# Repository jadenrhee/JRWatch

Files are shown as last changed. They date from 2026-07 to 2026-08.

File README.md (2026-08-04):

# JRWatch



A smartwatch designed from scratch, board included. 36 mm across and 4
layers, with an nRF52840 for Bluetooth, an nPM1300 handling charging and
the power rails, a BMI270 for motion, and a Sharp memory-in-pixel LCD
that holds a static image on about 12 µW. Firmware runs on Zephyr.

Most of the design work went into idle current, meaning what it draws
while sitting on a wrist doing nothing.

<p align="center">
  front copper
  back copper
</p>
<p align="center"><sub>Front copper on the left, back on the right. 36 x 36 mm, 4 layers.</sub></p>

| | |
|---|---|
| Sleep current | ~15 µA, or ~26 µA while advertising over Bluetooth (1.5 s interval, not connected) |
| Battery life | ~4 months connected to a phone all day, ~8 months mostly idle, on a 150 mAh cell |
| Firmware | Zephyr v4.1.0, 232 KiB flash / 40 KiB RAM |

These are calculated from datasheet typicals, not measured on hardware.
The full itemization is in the
[verification report](docs/verification-report.md). Part choices are in
the [design rationale](docs/design-rationale.md).

## Architecture

```mermaid
flowchart LR
  USB["USB-C"]
  BAT["LiPo 150 mAh<br/>+ 10k NTC"]
  PMIC["nPM1300<br/>charger, 2 bucks,<br/>2 load switches"]
  MCU["nRF52840<br/>MDBT50Q-1MV2"]
  DISP["Sharp LS013B7DH03<br/>128 x 128 MIP"]
  IMU["Bosch BMI270"]

  USB -->|VBUS| PMIC
  BAT -->|VBAT| PMIC
  PMIC -->|3V0 always-on| MCU
  PMIC -->|VDD_DISP via LSW1| DISP
  PMIC -->|VDD_IMU via LSW2| IMU

  MCU -.->|I2C 0x6b| PMIC
  MCU -.->|SPI2| DISP
  MCU -.->|SPI1| IMU
```

Solid lines are power, dashed are data. The display and IMU sit behind
load switches inside the PMIC. In armed sleep they draw about 4 µA and
6 µA. Ship mode disconnects the battery entirely and the whole watch
drops to 370 nA, low enough that cell self-discharge dominates. Full net
list is in [`hardware/skidl/jrwatch.py`](hardware/skidl/jrwatch.py).

<p align="center">
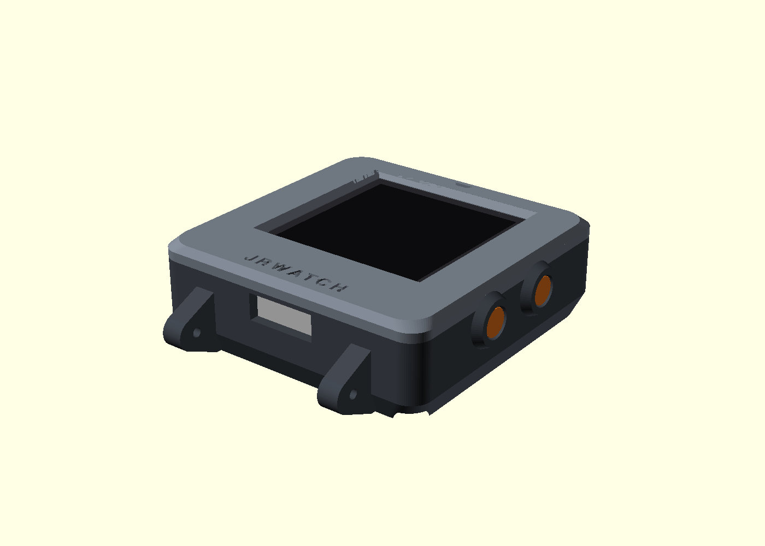
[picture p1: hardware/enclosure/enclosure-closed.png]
case
  
</p>

## Status

Not yet fabricated. A review before ordering turned up a problem with
the display connector, and both halves of it trace to one cause. The
panel's ribbon exits the center and has to fold 180 degrees back
underneath. That fold leaves roughly a 9 mm window where the connector
can sit, and mine was outside it. The fold also inverts the contact
face, which reverses the pin order, and I had the pins running straight
through.

The pin order is corrected in the schematic. Repositioning the connector
is a layout change and hasn't landed yet, so ordering is blocked.
Written up as D-025 in the [decision log](docs/decision-log.md).

## Firmware

An out-of-tree Zephyr board port with devicetree, Kconfig, and board
files. Three power modes cover active, armed sleep, and off. The display
redraws only when its content changes, and the IMU wakes the SoC on
motion. BLE reports battery level and step count
([protocol](docs/protocol.md)).

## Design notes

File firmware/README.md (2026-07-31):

# JRWatch firmware (Zephyr RTOS)

Vanilla-Zephyr application (pinned `v4.1.0` via `west.yml`) with a custom
board definition (`boards/jr/jrwatch/`) that mirrors the schematic pin map
exactly - the devicetree is generated-from/checked-against
`hardware/skidl/jrwatch.py`.

## Build

CI builds every push (`.github/workflows/firmware.yml`, Zephyr CI container).
Locally:

```sh
mkdir jr-ws && cd jr-ws
git clone https://github.com/jadenrhee/JRWatch jrwatch
west init -l --mf firmware/west.yml jrwatch
west update
west build -b jrwatch jrwatch/firmware
west flash   # SWD via TC2030
```

First-time flash is over SWD (Tag-Connect TC2030). USB DFU (MCUboot +
`slot1` partition is already laid out in the devicetree) is the documented
follow-up for cable-only updates.

## How the firmware maps to the power goals

| State | What runs | What's off | Budget driver |
|---|---|---|---|
| **SHIP** | nPM1300 only (battery disconnected from VSYS) | everything | PMIC ship mode ~ sub-µA; exit = SW1 ≥ 96 ms or USB plug |
| **IDLE** ("armed sleep") | nRF System ON idle + RTC (LFXO), BMI270 low-power any-motion @25 Hz, MIP panel statically holding the face, slow BLE adv (1-2 s) | display SPI quiet (image is retained in-pixel), CPU in WFI, BUCK1 off | the headline number - itemized in `docs/verification-report.md` |
| **ACTIVE** | display redraw *only on content change*, IMU 50 Hz, BLE connectable | - | 20 s inactivity drops back to IDLE |

Mechanisms:

- **Hardware power gating**: `VDD_DISP` and `VDD_IMU` are nPM1300 load
  switches (devicetree `npm1300_lsw_disp` / `npm1300_lsw_imu`), driven via
  the Zephyr regulator API. Before cutting the display rail the interface
  lines are quiesced so the unpowered panel is never back-fed (`ui.c`).
- **BUCK1 held off** at boot (`regulator-boot-off` + a runtime check) -
  it is the populated-but-unused 1.8 V experiment rail (decision D-012).
- **Wake sources**: BMI270 INT1 (any-motion) and SW2 both post to a
  `k_event`; between events the idle thread keeps the SoC in System ON idle
  with everything clock-gated. SW1 is wired to the PMIC's SHPHLD only.
- **Display never polled**: the frame is diffed as a string; identical
  content means zero SPI traffic, and the MIP panel holds the image at ~µW
  with the driver toggling EXTCOMIN at 1 Hz.
- **32.768 kHz crystal** (LFXO) for timekeeping and tight BLE sleep-clock
  accuracy - cheaper than LFRC + calibration (decision D-009).
- **Ship mode**: 5 s long-press on SW2, executed from the main loop:
  `regulator_parent_ship_mode()` (TASKENTERSHIPMODE) disconnects the
  battery. On USB power the request is refused up front (the PS forbids
  writing the task with VBUS present); a failed entry recovers the face
  instead of hanging.
- **Battery %**: nPM1300 charger measurements (VBAT/status via sensor
  channels) + an OCV table. Nordic's `nrf_fuel_gauge` (NCS) is the
  higher-accuracy drop-in when building under nRF Connect SDK.

Known follow-ups: on-chip BMI270 step counter (Zephyr driver
doesn't expose it; host-side estimator in `motion.c` meanwhile), BLE
Current Time Service for real wall-clock, MCUboot + USB DFU enablement.

## BLE GATT protocol

Advertises as `JRWatch`, connectable, 1-2 s advertising interval.
Preferred connection parameters 50-100 ms interval, latency 4.

| Service | Characteristic | UUID | Access | Format |
|---|---|---|---|---|
| Battery Service (0x180F) | Battery Level (0x2A19) | standard | read/notify | uint8 % |
| Motion (custom) | - | `6a570000-8f9d-4a7c-9b31-24d1c30f51aa` | - | - |
| | Step count | `6a570001-...` | read/notify | uint32 LE |
| | Activity state | `6a570002-...` | read | uint8 (0 idle / 1 active) |

Console/logs are on SEGGER RTT (no UART pins on the board).

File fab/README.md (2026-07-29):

# Fabrication package

Everything needed to order the JRWatch r1 board from JLCPCB.

## Order parameters (JLCPCB)

| Option | Value |
|---|---|
| Layers | 4 |
| Stackup | **JLC04081H-3313** (0.8 mm finished thickness) |
| Dimensions | 36 × 36 mm, rounded corners R6 |
| Min track/space used | 0.15 mm track / 0.13 mm gap (design rule floor 0.127 mm) |
| Min via | 0.45 mm / 0.2 mm drill (a few 0.48/0.2 vias between QFN pads) |
| Surface finish | **ENIG recommended** (0.5 mm QFN + 0.5 mm FPC pitch) |
| Copper | 1 oz outer / 0.5 oz inner (default) |
| Solder mask | any; silkscreen carries battery polarity + board ID only |

## Files

- `gerbers/` - RS-274X plots (`--no-x2`, mask-subtracted silkscreen) +
  Excellon drill + map. Zip this folder for the JLC order.
- `bom-jlcpcb.csv` - JLC format (`Comment,Designator,Footprint,LCSC`).
  Lines tagged `[HAND-PLACE]` are not for SMT assembly:
  - **U1** MDBT50Q-1MV2 and **U2** nPM1300 - LCSC listed but out of stock at
    design time; source from DigiKey and reflow by hand (module castellations
    iron-friendly; QFN with hot air/plate).
  - **J2** FPC connector - low LCSC stock, order early.
- `cpl-jlcpcb.csv` - pick-and-place. JLC's viewer often needs per-part
  rotation nudges (especially QFN/SOT); footprints should be verified in
  their preview before the order is confirmed.
- `renders/` - top / bottom / iso PNG renders and copper-layer SVGs.
- Connectivity reference for assembly/bring-up: `hardware/netlist/jrwatch.net`
  (generated) - the schematic source of record is `hardware/skidl/`. The old
  `schematic-reference.pdf` was removed: it predated the D-025 J2 pinout fix
  and published the reversed display connector pin order.

## Order status

**This revision is not ready to order.** Pre-order review (D-025) found the
display connector placed out of the panel tail's reach and with un-mirrored
pin order. The schematic is corrected and re-verified; the corresponding
layout rework has not landed yet.

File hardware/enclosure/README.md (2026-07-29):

# Enclosure

Two-piece 3D-printable watch case, written as parametric OpenSCAD
(`jrwatch_case.scad`).
Every cutout is measured from the actual board file: the USB-C slot, the two
side-button bores, and the display aperture. The board has no mounting
holes, so the case clamps it at the four corner arcs, which I verified are
component-free on both sides.

**This revision tracks the pre-D-025 board.** The D-025 layout rework moves
the display connector (and with it the FPC relief, the aperture offset, and
the display mounting stack), so the case geometry and STLs get reworked with
it - don't print or order a set until that lands.

| Exploded | Assembled |
|---|---|
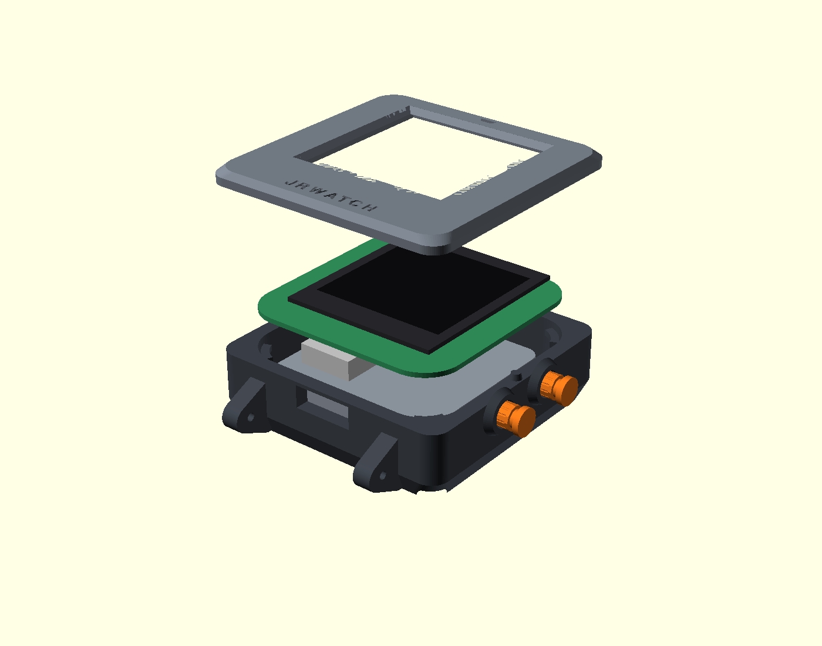
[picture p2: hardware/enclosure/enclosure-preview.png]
exploded
|  | closed |
| **Section through the USB slot** | **Case back** |
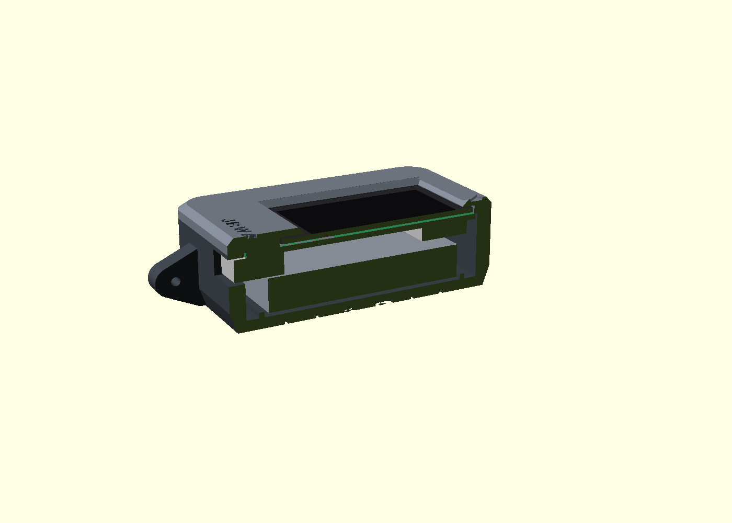
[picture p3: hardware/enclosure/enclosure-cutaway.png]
cutaway
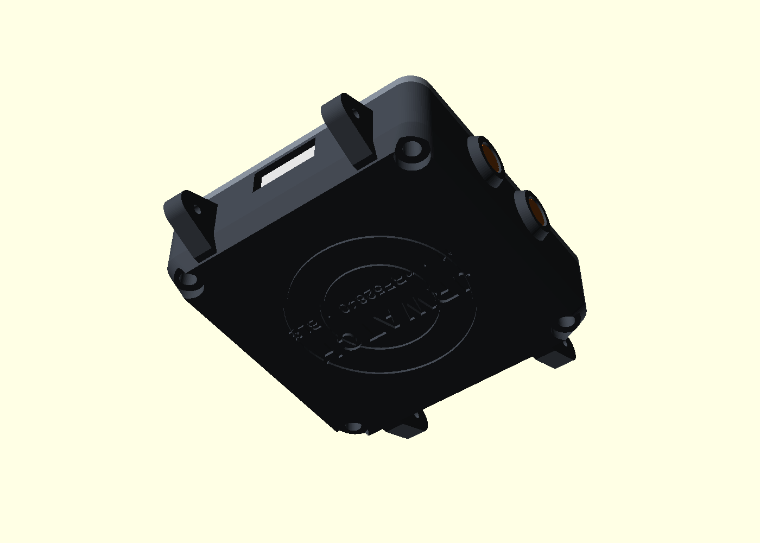
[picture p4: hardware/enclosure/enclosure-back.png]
back
|  |  |

Tapered body with filleted edges, curved lugs drilled for 22 mm spring bars,
knurled sliding pushers in guarded pods, recessed USB-C port. Engraved
12-o'clock index, wordmark, and case back.

## Printed parts (`stl/`)

| File | Qty | What it is |
|---|---|---|
| `case-shell.stl` | 1 | Bottom shell: battery bay, component headroom, USB port, pusher pods, lug horns, engraved back |
| `case-bezel.stl` | 1 | Top ring: display pocket, FPC relief, chamfered aperture, index + wordmark |
| `case-button.stl` | 2 | Knurled sliding pushers (drop into the east-wall bores from the inside) |

Overall 41.4 × 41.4 × 13.6 mm plus lugs. Fits a 22 mm spring-bar strap.

## Ordering online

Upload the three STLs to any print service - [JLC3DP](https://jlc3dp.com)
(same account as the PCB order), Craftcloud, or Shapeways. Choose:

- **Process/material**: MJF or SLS, PA12 nylon (strong, accurate, no
  supports). Gray or dyed black. Expect roughly $5-15 for the set.
- Resin (SLA, "Tough" type) also works and looks smoother; avoid standard
  brittle resin for the lugs.
- FDM at home works if printed shell-open-side-up and bezel-top-down with
  supports in the USB slot; holes may need a 2 mm drill pass.

No metal-plated or metal-filled materials: the BLE antenna sits at the north
edge and the case must stay RF-transparent there.

## Other hardware

| Item | Spec | Note |
|---|---|---|
| Screws ×4 | M2 × 12 mm self-tapping, pan head | enter from the back, bite into the bezel |
| Spring bars ×2 | 22 mm, Ø1.3-1.5 tips | standard watch part |
| Strap | any 22 mm | |
| Display adhesive | 0.3 mm double-sided tape (3M 9448A or VHB) | frame the glass edges, keep the active area clear |
| Battery pad | 1-2 mm foam tape in the battery bay | |

## Assembly order

1. Drop the two button pins into the east-wall bores, flange inward.
2. Battery (502030, PCM-protected) into the bay, pad under it, pigtail up
   to J3 - **check polarity with a meter first** (board silk marks + / −).
3. Board in, components down, USB-C aligned to the south slot. It seats on
   the four corner pads.
4. Fold the display FPC into J2 (contact face up after the fold - J2 is
   top-contact, D-025; flip the latch), tape the
   panel onto the board top with the tail at the south edge.
5. Bezel on, 4 screws from the back. Don't overtighten - stop at contact
   plus a quarter turn.

## Regenerating

```
openscad -D 'PART="shell"'  -o stl/case-shell.stl  jrwatch_case.scad
openscad -D 'PART="bezel"'  -o stl/case-bezel.stl  jrwatch_case.scad
openscad -D 'PART="button"' -o stl/case-button.stl jrwatch_case.scad
```

All key dimensions (stack heights, clearances, lug size) are parameters at
the top of the file.

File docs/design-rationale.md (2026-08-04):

# Design rationale, block by block

Why I picked what I picked. Where there was a real alternative I wrote it
up in `decision-log.md` (the D-numbers below); part sourcing details are in
`hardware/parts.yaml`.

## System architecture

```
USB-C ──► nPM1300 PMIC ──► BUCK2 3.0V (always-on) ──► nRF52840 module
 5V/CC      │  ▲                │                        │  │  │
            │  └─ LiPo 150mAh   ├─ LSW1 ─► VDD_DISP ─► Sharp MIP 128×128
            │     + 10k NTC     └─ LSW2 ─► VDD_IMU  ─► BMI270
            └─ VBUSOUT ─► module VBUS (USB detect/DFU)
```

One always-on rail, two hardware-gated domains, everything else dead in
sleep. If a part can leak current, it doesn't stay electrically attached
while the watch is idle. The sleep numbers follow from that.

## BLE SoC - Raytac MDBT50Q-1MV2 (D-001, D-010)

nRF52840 with the antenna already tuned and certified (FCC/CE/TELEC).
A bare chip + meandered-F antenna needs VNA matching this project can't do;
an untuned antenna silently costs link budget -> retransmissions -> battery.
The module still demands real layout discipline: 61 castellations, a
hard 12.4 × 3.8 mm all-layer keep-out, and radio-adjacent pins that are
restricted to low-frequency signals (datasheet §2.6). The pin map respects
that restriction, with only buttons and EXTCOMIN on those pins. Datasheet:
Raytac spec Ver.K.

## PMIC - Nordic nPM1300 (D-002, D-011, D-012)

One chip covers the whole power path: linear LiPo charger with
NTC/JEITA windows, two 200 mA bucks, two load switches, USB-C sink
detection, ship mode (370 nA), and the measurement chain for Nordic's fuel
gauge. Bucks are asymmetric in their VSET tables, which decided the rail
plan: **BUCK2 = 3.0 V via a 150 kΩ strap is correct at power-on with zero
firmware involvement**; BUCK1 (1.8 V per the reference config) is populated
but held off. The rail is 3.0 V because every load (module 1.7-3.6 V, IMU
1.71-3.6 V, display 2.7-3.3 V typ 3.0) is happy there and it maximizes the
usable LiPo discharge window. Charge current 76 mA ~ 0.5 C for the 150 mAh
pack.

## IMU - Bosch BMI270 (D-003)

The common choice in shipping wearables, picked for its 5.9 µA low-power
accel mode with a hardware any-motion interrupt, so the SoC can stay asleep
until the wrist moves. SPI (not I2C) keeps active-mode transactions short; VDDIO
rides the always-on rail so the interface stays defined while VDD is gated
(explicitly allowed by the datasheet); unused aux/OIS pins strapped per
Table 22.

## Display - Sharp Memory-in-Pixel LS013B7DH03 (D-004, D-013)

Chosen on power. The panel retains its image at 12 µW typical, so the watch
face costs ~4 µA while the system sleeps, with no backlight and readable in
sunlight. A GC9A01-class TFT draws three orders of magnitude more. The costs:
10-pin FPC assembly, a 1 Hz EXTCOMIN toggle (driven by a timer, not the CPU;
EXTMODE strapped high), and 128×128 mono aesthetics. Firmware only redraws
when content changes.

## USB-C (D-015, D-019)

Charge + Full-Speed data (nRF52840 USB for DFU). CC lines go straight to
the nPM1300, which implements Type-C sink detection internally, so the
classic 5.1 k pull-downs would be wrong here, not just redundant. ESD
(USBLC6-2SC6) sits in the data path; VBUS enters through one merged pad
pair (each physical pad on this connector already bridges A/B) with an
IPC-2221-verified width.

## Controls (D-014)

Two side buttons. SW1 goes **only** to the PMIC's SHPHLD pin. That node
swings to VBAT and must never meet an nRF GPIO; it wakes the board from
ship mode in hardware. SW2 is the user button on P1.13 with GPIO SENSE
wake; that pin is one of the radio-restricted low-frequency ones, which is
fine for a button. Both lines: 100 Ω series + SOD-923 TVS sized to their voltage
domains (5 V part on the VBAT-domain node, 3.3 V part on the logic node).

## Timekeeping (D-009)

A watch drifts minutes per week on the RC oscillator; the FC-135-class
32.768 kHz crystal costs two 0402 caps and *saves* current (no periodic
HFCLK calibration, tighter BLE sleep-clock windows -> shorter radio-on).

## Board & layout (D-007, D-020..D-022)

36 × 36 mm R6, 4-layer 0.8 mm (JLC04081H-3313): L1 top = display side +
escape routing, In1 = power pours (3V0/VSYS/VBUS/VBAT), In2 = solid ground,
L4 bottom = components. Antenna strip at the north edge, USB south, buttons
east, battery west, PMIC + inductors clustered with hand-routed switch
loops. The display panel occupies the top face; the FPC connector hides
under its south edge. Silkscreen carries only what matters at assembly:
battery polarity and the board ID.

## Firmware (see firmware/README.md)

Zephyr with a custom board definition pin-mapped 1:1 from the SKiDL source.
Event-driven; three power tiers (ACTIVE / armed-sleep IDLE / PMIC ship
mode); rails gated through the regulator API; display treated as
write-only-on-change. Console over RTT because the design spends no pins on
UART.

## Not included (and why)

- Charge LED (D-016): invisible in a case, and it would wreck the µA budget.
- PPG heart rate (stretch in the brief): omitted to protect the core
  power/size goals; the gated `VDD_IMU` domain and spare module pins are
  where a future MAX30101 daughter experiment would land.
- NFC antenna: module pins exist, but there is no use for it on this product.
- Bare-chip + tuned trace antenna respin: documented stretch once a VNA
  is available (D-001).

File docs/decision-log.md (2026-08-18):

# Decision Log

Every non-trivial design decision, the options considered, and the reasoning.
Priorities used to break ties, in order:

1. **Demonstrable, measured low-power design** (headline metric: sleep current / battery life)
2. **Manufacturability + reliability for a solo builder** (hand-solderable, certified RF, JLCPCB-friendly)
3. **Small, clean, dense layout** (wearable form factor)
4. **Clarity of process/rationale**

---

## D-001: BLE radio - pre-certified module vs. bare nRF52840

- **Options:** (a) Raytac MDBT50Q-1MV2 module (nRF52840 inside, integrated antenna,
  FCC/CE/TELEC certified); (b) bare nRF52840-QIAA + meandered-F trace antenna.
- **Decision: (a) Raytac MDBT50Q-1MV2.**
- **Why:** A trace antenna requires matching-network tuning with a VNA that is not
  available; an untuned antenna silently costs link budget and battery (retransmissions),
  which attacks priority #1. The module is pre-certified (priority #2), still demands
  real high-density layout around its castellations and an antenna keep-out (priority #3),
  and its datasheet gives an explicit keep-out rule that can be *verified* (priority #4).
- **Cost accepted:** ~$6 module premium vs. bare chip; module footprint is larger than a
  bare QFN. Documented stretch goal: respin with bare nRF52840 + tuned antenna once a VNA
  is available.

## D-002: Power management - integrated PMIC vs. discrete chain

- **Options:** (a) Nordic nPM1300 (linear charger + 2 bucks + 2 load-switch/LDOs +
  fuel-gauge measurement chain + USB-C CC detection + ship mode, one QFN32);
  (b) discrete: MCP73831 charger + MAX17048 fuel gauge + low-Iq LDO + discrete load
  switches.
- **Decision: (a) nPM1300**, with (b) held as a logged fallback if LCSC sourcing fails.
- **Why:** Power management *is* the project story. The nPM1300 gives coulomb-counting
  class fuel gauging (VBAT/IBAT/temp measurement feeding Nordic's fuel-gauge algorithm),
  hardware ship mode (~µA off-state), programmable charge current, and two load-switch
  outputs used here to hard-gate the display and sensor rails in ship mode. Gating in
  hardware leaves no sneak paths, so the off-state figure is real rather than
  rhetorical (priority #1). One QFN32 replaces 4+ packages (priority #3) and is a part
  Apple/Nordic-adjacent interviewers recognize (priority #4).
- **Risk accepted:** QFN-32 0.4 mm... *(pitch verified against datasheet in D-010)*
  reflow requires hot-air/stencil rather than an iron; acceptable for a solo builder
  with paste + hot plate, and JLCPCB can assemble it if hand assembly fails (priority #2).

## D-003: IMU - Bosch BMI270

- **Options:** (a) Bosch BMI270; (b) ST LSM6DSO.
- **Decision: (a) BMI270.**
- **Why:** Wearable-industry-standard low-power IMU (5.9 µA low-power accel mode with
  any-motion interrupt - exactly the motion-wake mechanism this design needs), built-in
  step counter offloads counting from the SoC so it can sleep (priority #1), Zephyr has
  an in-tree driver (priority #2), and it connects to hands-on Bosch internship
  experience (priority #4). LSM6DSO is an equivalent fallback if stock fails.

## D-004: Display - Sharp Memory-in-Pixel LCD

- **Options:** (a) Sharp MIP LCD LS013B7DH03 (1.28", 128×128, SPI);
  (b) GC9A01 round TFT (240×240, SPI).
- **Decision: (a) Sharp MIP LS013B7DH03.** *(Supply voltage and FPC pinout verified
  against the Sharp datasheet in D-011 before committing the schematic.)*
- **Why:** Power decides this one. The MIP panel holds a static image at
  single-digit-µW (it only draws meaningful current while lines are being rewritten),
  needs no backlight, and stays readable in daylight, so the watch face costs ~µA
  average. A GC9A01 TFT draws tens of mA with backlight on and ~mA-class even dimmed;
  it would destroy the armed-sleep budget, which is the headline number (priority #1).
  MIP sourcing is via Digi-Key/Mouser/Adafruit rather than LCSC. That is acceptable
  because the display is a hand-attached FPC module, never JLC-assembled; only its
  10-pin FPC *connector* must be LCSC-stocked (priority #2).
- **Logged:** GC9A01 kept as the documented fallback if MIP sourcing collapses.

## D-005: System rails and power-gating topology

- **Options considered:** (a) single 3.0 V always-on buck + load-switch-gated peripheral
  domains; (b) dual rails 1.8 V + 3.3 V both always-on; (c) 1.8 V logic rail + 3.0 V
  peripheral rail.
- **Decision: (a)** BUCK2 = 3.0 V always-on (VSET2 strap = 150k) feeding the MDBT50Q
  (VDD), pull-ups, and bus IO; nPM1300 **LSW1 gates the display** 3.0 V domain and
  **LSW2 gates the IMU (+ future PPG) domain**, both fed from the 3V0 rail. BUCK1 is
  populated but unloaded by default (available as a 1.8 V experiment rail, VSET1 = 47k;
  held off in firmware for production power figures - D-012).
- **Why:** Every always-on rail costs quiescent current; one hysteretic-mode buck is the
  minimum viable always-on domain (priority #1). Full hardware gating of display+sensors
  removes their leakage entirely in ship mode and prevents sneak back-feed
  paths through GPIO (verified in the leakage review). 3.0 V (not 3.3 V) is chosen
  because every load (nRF52840: 1.7-3.6 V, BMI270: 1.71-3.6 V, Sharp MIP: 2.7-3.3 V
  typ 3.0 V) is happy there, it maximizes usable LiPo discharge range through the buck,
  and it is the MIP panel's nominal supply.
- **Nuance logged:** BMI270 VDD could run from a 1.8 V rail for ~40% sensor energy
  savings, but that adds an always-on second buck whose quiescent current exceeds the
  saving at the ~6 µA sensor budget of this design. Rejected on net-µA math.

## D-006: Sleep-state architecture (drives all later verification)

Three power tiers, each with a projected budget to be computed part-by-part in
`docs/verification-report.md`:

1. **Ship / off** - nPM1300 ship mode, SYS rail dead, wake by SHPHLD button only.
   Target: < 1 µA from battery.
2. **Watch idle (armed sleep)** - the headline number. nRF52840 in System ON idle with
   RTC + full RAM retention (BLE off or long-interval advertising), BMI270 in low-power
   any-motion mode (its INT1 wakes the SoC), display statically holding the watch face
   (EXTCOMIN toggled at 1 Hz by the display driver - a periodic ~µs CPU wake), display+IMU
   rails ON but idle. Target: **≤ ~20 µA total** -> months on a 150 mAh cell.
3. **Active** - BLE connected, display refresh on change only, IMU at 50 Hz.

- **Why this structure:** it maps 1:1 to what wearable teams actually ship (off / wrist-
  down / wrist-up), and every number in it is measurable at bring-up with a µCurrent or
  PPK2, so the headline figure can be replaced by a measurement before anyone quotes it.

## D-007: Board format - 4-layer, ~36 mm rounded square, 0.8 mm thick

- **Decision:** 36 × 36 mm rounded-square outline (R = 6 mm), JLCPCB 4-layer,
  **0.8 mm** finished thickness (JLC04081H-3313 stackup), layers:
  L1 components/signal, L2 (In1) power pours, L3 (In2) solid GND, L4
  signal/components.
- **Why:** The Sharp 1.28" panel (~27 × 28 mm active module) sets the minimum face size;
  36 mm is small-watch territory and leaves a real antenna keep-out strip plus button /
  USB edge room (priority #3). A dedicated unbroken GND plane (In2) on the 4-layer
  stack keeps the PMIC switching loops and module grounding verifiable
  (priority #1); 0.8 mm halves stack height in a wearable and is a standard JLC 4-layer
  offering (priority #2). USB is FS-only (12 Mbps) over ~15 mm - controlled impedance
  is not required; the pair is still routed tightly coupled and length-matched as good
  practice.

## D-008: Programming/debug - Tag-Connect TC2030 + USB DFU

- **Decision:** TC2030-IDC-NL footprint (no connector BOM cost, zero height) for SWD,
  plus nRF52840 USB DFU (factory Nordic bootloader is absent on Raytac modules -
  a UF2/MCUboot bootloader is flashed once over SWD, then USB DFU serves daily
  development). Tag-Connect lands on the SWDIO/SWCLK castellations; no 10-pin
  Cortex header fits a 36 mm watch.
- **Why:** Space (priority #3) and solo-builder practicality (priority #2).

## D-009: 32.768 kHz timekeeping crystal - include it

- **Options:** (a) external 32.768 kHz crystal (Epson FC-135 class) on P0.00/P0.01;
  (b) internal LFRC oscillator.
- **Decision: (a) external crystal.**
- **Why:** On a watch, LFRC's ±250 ppm-class error is minutes/week of drift, and
  it costs more current than the LFXO once calibration wakeups are counted
  (LFXO ~ 0.23 µA vs LFRC ~ 0.7 µA + periodic HFCLK calibration bursts on nRF52840).
  Crystal accuracy also tightens BLE sleep-clock windows -> shorter radio-on time per
  connection event (priority #1). Cost: one 3215 crystal + 2 caps (18 pF, set from
  the FC-135 CL spec against nRF52840 pin capacitance - calc in verification report,
  refit in D-026).

---

## D-010: Module sourcing - LCSC listed but out of stock; keep MDBT50Q-1MV2 via DigiKey

- **Finding (2026-07-02):** LCSC lists every Raytac variant - MDBT50Q-1MV2 = C5118826
  ($6.83), P1MV2 = C5119772, U1MV2 = C2688382 - but all show **zero stock**. DigiKey has
  MDBT50Q-1MV2 in stock, ships today.
- **Options:** (a) keep 1MV2, source DigiKey, hand-place; (b) swap to an LCSC-stocked
  non-Raytac module (e.g. Ebyte E73-2G4M08S1C); (c) wait for restock.
- **Decision: (a).** The module's castellated pads are the most iron-friendly
  package on the board, so hand-placing it costs nothing in practice (priority #2
  intact), and Raytac + nRF52840 is the wearable-industry-standard combination the
  project depends on (priorities #1/#4). The KiCad footprint accepts 1MV2 and P1MV2
  interchangeably (identical pads per datasheet §2.1), so a future JLC-assembled run can
  use whichever variant LCSC restocks - C-numbers recorded in `hardware/parts.yaml`.
- **Verified datasheet rules to carry into layout:** antenna keep-out **12.4 mm wide ×
  3.8 mm deep, all layers, no copper**, extending ~1 mm beyond both module sides; plus a
  1.6 × 1.2 mm top-layer-only keep-out notch 2.95 mm from the module's left edge;
  module placed with antenna at the board edge (DS §2.2-2.3, Ver.K).

## D-011: nPM1300 sourcing - same situation, same call

- **Finding:** nPM1300-QEAA-R7 = LCSC C7501206, listed, **zero stock**; WLCSP variant
  (CAAA) in stock but not hand-solderable - rejected. DigiKey: $2.95, ships today.
- **Options:** (a) keep nPM1300, DigiKey, hand hot-air reflow; (b) invoke the discrete
  fallback (MCP73831 + MAX17048 + LDO + 2× load switch, all LCSC basic).
- **Decision: (a).** The fallback would cost the design its ship mode, hardware
  power-gating, coulomb-counting-class fuel gauge, and USB-C detection (i.e. the
  measurable low-power architecture that is priority #1) in exchange for fixing a
  sourcing gap that DigiKey already fills. QFN32 @ 0.5 mm pitch with a 3.5 mm EP
  (PS mech spec) reflows fine with paste + hot plate. The two hand-place lines (U1, U2)
  are exactly the two parts a JLC economic-assembly order can't place today; everything
  else on the BOM is LCSC-stocked, so the board still assembles as
  "JLC does the fiddly passives, builder places two ICs."

## D-012: Rail strapping - BUCK2 is the system rail (3.0 V at power-on, no firmware needed)

- **Finding:** nPM1300 buck startup voltages are strapped by VSET resistors, and the two
  tables are asymmetric: VSET1 tops out at 2.7 V (250-500 kΩ), while **VSET2 = 150 kΩ
  gives exactly 3.0 V** (PS BUCK chapter).
- **Decision:** System 3V0 rail = **BUCK2, VSET2 = 150 kΩ 1%** -> correct-by-hardware at
  first power, no I2C bootstrap dependency for the SoC supply. BUCK1 is populated per
  Nordic reference configuration 1 (L + caps + VSET1 = 47 kΩ -> 1.8 V) but **disabled by
  firmware at init** - it exists as a validated-by-datasheet 1.8 V experiment rail
  without inventing an un-datasheet-ed "unused buck" strapping. Its disable is a checked
  item in the verification report's leakage review.
- **Load switches:** LSW1 ← 3V0 -> display VDD/VDDA; LSW2 ← 3V0 -> IMU VDD.
  (LSIN1/LSIN2 wired from BUCK2 output, load-switch mode, so ship mode can cut both
  domains completely.)

## D-013: Display connector - Hirose FH12A, low stock flagged

- FH12A-10S-0.5SH(55) = C5139870, **91 units** in stock. No drop-in substitute: the
  plain FH12 (C506791) is bottom-contact and cannot mate the folded-under tail (D-025).
  Kept: it's the proven connector for this panel family (Adafruit breakout uses FH12),
  KiCad ships the exact footprint, and the build needs 1-2 units - but flagged in
  `parts.yaml` to order early. Display module itself (LS013B7DH03, VDD 2.7-3.3 V
  verified from Sharp spec §6-1, 12 µW static typ §6-4) ships from DigiKey/Adafruit and
  is hand-attached - never JLC-assembled, so LCSC stock is not required for it.

## D-014: Button architecture - power button on SHPHLD, user button on GPIO

- **Constraint found in PS:** SHPHLD has an internal 50 kΩ pull-up to the battery
  domain - the node swings to VBAT (up to 4.2 V), which exceeds the nRF52840 GPIO
  absolute max (VDD + 0.3 V). The two nets must not share a button naively.
- **Decision:** SW1 = power button -> nPM1300 SHPHLD only (ship-mode exit ≥ 96 ms press,
  also readable as a PMIC event over I2C/GPIO interrupt). SW2 = user button -> nRF
  P1.13 with internal pull-up (uses a radio-adjacent "low-frequency-only" module pin,
  which buttons are perfect for) - GPIO SENSE wakes the SoC from System OFF.
  Both lines get 100 Ω series + a TVS at the switch (user-touchable nets): D2 =
  ESD9B3.3 on the SW2/GPIO line (3V0 domain), D1 = **ESD9B5.0** on the SW1/SHPHLD
  line, since that node rides the battery domain (up to ~5 V), where a 3.3 V-working
  part would sit in clamp. No external pull-ups -> zero standing current either
  way (priority #1).

## D-015: No discrete USB-C CC pull-downs - nPM1300 does Type-C detection

- The task brief specified 5.1 kΩ CC pull-downs; the nPM1300 PS reference circuit
  connects CC1/CC2 straight to the receptacle because the PMIC implements USB Type-C
  sink detection (100/500/1500 mA input-limit negotiation) internally. **Datasheet wins;
  resistors deleted.** Logged as a deliberate deviation from the brief, per its own
  "follow the datasheet, document why" escape hatch.

## D-016: No charge LED

- nPM1300 offers 3 LED drivers; a charge LED at ~2 mA would dwarf the entire sleep
  budget if left on and is invisible inside a watch case anyway. Charge status is
  reported via the fuel-gauge/charger registers -> BLE Battery Service and the
  watch face. PMIC GPIO0 is wired to nRF P0.12 as the charger/fuel-gauge interrupt
  line instead. (Priority #1 over blinkenlights.)

## D-017: On-board NTC (10 kΩ, populated)

- Small hobby LiPo packs frequently omit the thermistor lead; the nPM1300 requires NTC
  or an explicit register disable. Populating a board NTC (Murata NCP15XH103F03RC,
  10 k B3380 1%, placed at the battery connector) keeps hardware charge-temperature
  protection real (JEITA windows in the charger) instead of software-disabled, which
  matters on something strapped to a wrist. If a pack with its own
  NTC is chosen later, the board part is depopulated and the pack lead lands on the
  same net (noted in human-review checklist).

## D-018: Bus strapping and idle-current hygiene

- I2C (PMIC, 400 kHz): 4.7 kΩ pulls to the always-on 3V0 rail - idle-high bus burns
  zero standing current; PMIC must stay reachable in every sleep state, so its bus
  cannot live on a gated rail.
- BMI270 CSB: 100 kΩ pull-up to the always-on 3V0 rail (deselected during nRF reset
  when GPIOs float). The pull is not on the gated rail because CSB must be held
  deselected *before* VDD_IMU comes up; the only state with 3V0 up and VDD_IMU down
  is the millisecond-scale boot window (ship mode kills 3V0 too), so there is no
  steady-state back-feed path through the pull.
- Display SCS: 100 kΩ pull-down (Sharp SCS is active-high; float-low keeps it
  deselected; a pull-down holding an idle-low node costs zero current).
- ASDx/ASCx (BMI270 aux bus, unused): tied to VDDIO per DS Table 22; OCSB/OSDO: DNC.
- All strapping resistors chosen so that **every pull is toward its net's idle state**
  -> 0 µA standing current across the board (verified line-by-line in the report).

## D-019: USB-C VBUS wired at one merged pad pair

- **Finding:** on the HRO 16-pin footprint each *physical* VBUS pad is already
  the merged A/B pair (A4/B9 on one pad, A9/B4 on the other), so a single pad
  delivers VBUS in both plug orientations; the second pad only adds current
  capacity. The west pad is boxed in by an NPTH shell post, the CC2 pad and
  the shield pad - connecting it forced clearance violations in every variant
  tried.
- **Decision (as originally routed):** wire the east pad only (0.3 mm entry + via
  into the In1 VBUS plane); the unwired pad noted here rather than silently left.
- **Superseded during later routing:** a south exit was found for the west pair
  (0.35 mm trace into a via at the connector's south edge), and both merged pad
  pairs are now wired into the In1 plane. The 0.3 mm entry remains the narrowest
  external section of the VBUS path (IPC-2221 calc in the verification report §5).

## D-020: Copper clearance rule 0.15 -> 0.13 mm

- Mid-routing the default clearance was lowered to 0.13 mm (all net classes).
  JLCPCB's 4-layer capability floor is 0.09 mm, so 0.13 keeps ~ 45 % margin
  over fab limits while opening the QFN escape lanes that made the PMIC
  fan-out routable (the 0.5 mm-pitch pad gaps admit 0.48/0.2 mm vias at 0.13,
  not at 0.15). All pre-existing routing was done at 0.15 and passes trivially.

## D-021: Solid zone connections (no thermal reliefs)

- Starved-thermal DRC violations on dense 0402 ground pads were eliminated by
  switching all pours to solid connection. Tradeoff: hand-iron rework of
  ground pads needs more heat; JLC reflow and hot-air work are unaffected.
  Chosen because the alternative (per-pad spoke tuning) added no electrical
  value on a board with a dedicated In2 ground plane.

## D-022: Seven links left open in the U2 south-west quadrant

- Seven links in the congested U2 south-west quadrant could not be closed
  without clearance violations; every attempt collided with other nets'
  copper. Rather than force them in, each was documented with exact endpoints
  and the surrounding copper that blocks it. The board is otherwise DRC-clean
  (zero violations), and the fab README gates ordering on closing them.

## D-023: Review pass closed the three power-critical links

- A dedicated layout review re-attacked the seven open links against a full
  survey of the local copper, instead of the earlier incomplete obstacle
  model. Result: VBAT (pin 19), VSYS pin 20 and VSYS
  pin 4 (PVDD) are now routed and DRC-clean. This took relocating the NTC
  trace out of the south-west slot, one drill resize on a cluster via, a
  via at the VBAT pour edge, a via-less B.Cu path for pin 20 onto existing
  VSYS copper, and an In1 connection lane under the PMIC exposed pad.
  These three links were mandatory: pin 20 is the PMIC's VSYS output, so the
  board was electrically dead without them.
- The remaining four (DISP_SCK, 3V0 to pin 12, SHPHLD, CC2) were also
  attempted: ripping and re-laying 13 corridor nets closed SHPHLD but broke
  I2C_SCL in exchange, so that state was reverted.
  Manual analysis shows each survivor is blocked by locked routing (the
  USB_DP via sits 0.45 mm under pin 12's pad mouth) or requires multi-net
  shoves that could not be made safely without a full re-lay. They stay documented in the review
  checklist with the updated analysis; closing them interactively is the
  remaining pre-order work.

## D-024: Ground-island stitching (correction to earlier assessment)

- The 16 zone-island ratsnest entries were previously described as cosmetic.
  Review showed the opposite: every island carries real component ground
  pads (IMU ground pins, decoupling-cap returns, the USB ESD ground, both
  buttons), which floated without a via to the In2 plane. A clearance-checked
  stitching pass added 13 vias; three
  islands (C1.2, C9.2, C21.2/C22.2 - four capacitor ground pads) have no
  legal via site without moving adjacent routing and are listed in the
  checklist for the same interactive session.

## D-025: Display connector placement and pin order are wrong - found at pre-order review

- Sharp's outline drawing (LS013B7DH03 spec fig 8-1) shows the FPC tail
  **centered** on the panel (13.3 mm from the panel edge) with terminal 1 on
  the **right** in the front view, contacts on the tail's back side, and a
  mandatory fold away from the polarizer. Consequences for this board:
  1. J2 at x=89.3 is unreachable - with the panel on the board, the tail
     center can only fall between x=95.3 and x=104.7. J2 must move to x=100.
  2. After the 180-degree fold the contact face flips up and left-right
     reverses as seen by the connector: pad k must carry panel terminal
     (11-k). The schematic and netlist are corrected (this commit); ERC 0/0.
     The FH12A (top-contact) is the right part for this mounting.
  3. The active area is 1.85 mm north of panel center - enclosure aperture
     offset corrected to 4.2 mm in a follow-up.
- Layout consequences (verified by trial re-route, then reverted to keep the
  board in a known-good state): J2 belongs at pads y~109.8 so its body sits
  between the USB-C shell-leg pairs at (95.7/104.3, 114.65) and the tail
  folds between them; the J2 MP pads need trimming (custom footprint) to
  clear the leg holes; the USB_DM_CONN crossover descent at x=99.85 crosses
  the new pad row and must be redesigned north of y~109; the display fan
  re-routes south from the module (trial run closed it plus SHPHLD and
  I2C_SCL cleanly). Ordering is blocked until this lands.
- Second review session findings (branch `d025-layout-wip` holds the work in
  progress): the USB-C shell has four top-protruding solder slots at
  (95.68/104.32, 110.47 and 114.65) that bracket the whole south strip, so
  the connector cannot sit south of the panel at all. Final verified
  position: J2 at (100, 107.75) - pads y=105.9, body fully under the panel
  (which mounts on 1.2 mm foam so its terminal ledge clears the 1.0 mm body),
  tail folding at the board edge between the leg columns. Proven on the
  branch: J2 placement + mirrored nets, USB CONN highways re-laid at
  y=107.95/108.35, the DM crossover loop, CC2 landing directly on J1.B5 via
  a (98.24, 108.87) via, CC1 landing from the north-east, and a
  zero-violation checkpoint with the display fan, I2C, SHPHLD and CC pair
  routed. Remaining: the south-quadrant fabric (strap highways, DISP_SCK
  east path, 3V0 pin 12, pin 28/29 pocket) needs one interactive-router
  session; every attempt so far has simply undone the one before it.
- **Correction (third pass):** (100, 107.75) does not work with the stock
  FH12 footprint. Its MP tabs span y 108.05-110.25 and J1's pad field starts
  at y 108.83, so the two connectors want the same space. DRC stays quiet
  about it because both nets are GND, which is why the earlier passes read
  as clean. The MP trim this entry already called for is what resolves it:
  tabs re-cut to y 107.00-108.58, clearing J1 by 0.25 mm and keeping
  2.84 mm2 of the 3.96 mm2 anchor by growing north into free space rather
  than only cutting south. Landed with the mirrored pad order on branch
  `d025-rework`, together with DISP_ON, EXTCOMIN, VDD_DISP, DISP_MOSI and
  part of DISP_CS. DISP_SCK, the rest of DISP_CS, 3V0 pin 12, SHPHLD, CC2
  and three GND zone links are still open. Each is blocked by geometry
  rather than effort: U2 is a QFN on 0.5 mm pitch, so nothing fits between
  adjacent pins, and the In1 3V0 pour does not start until x = 100, so a
  via dropped straight under pin 12 lands on the VSYS island instead.
  Closing them means working the corridor east of the pin row by hand.
  Ordering stays blocked.

## D-026: LFXO load caps refit 12 pF → 18 pF (calculation error found on review)

- **What happened:** the original fit used C = 2·(CL - Cs) with Cs = 6.5 pF as a
  *per-side* stray - a formula that only holds when Cs is the lumped parallel
  stray. With per-side stray the crystal sees CL_eff = (C + Cs)/2, so the fitted
  12 pF landed at ≈ 9.25 pF against the Q13FC13500004's 12.5 pF spec - tens of
  ppm fast, seconds per day, on a design that rejected the LFRC over drift
  (D-009).
- **Fix:** C = 2·CL - Cs ≈ 18.5 → **18 pF** (C16/C17), giving CL_eff ≈ 12.25 pF
  under the same stray estimate - and closer to spec than 12 pF for any
  plausible stray, so the swap is safe even though the estimate is soft.
  Changed in the schematic source and parts.yaml; the 18 pF LCSC number gets
  picked and stock-verified at order time. Netlist/board/fab outputs still
  carry 12 pF until they regenerate with the D-025 respin.
- **Verify at bring-up:** measure actual ppm (GPS/NTP comparison over 24 h or a
  counter on the LFCLK test point) before trusting the RTC spec; the pads are
  0402 and a value swap is trivial.

---

*Layout-phase constraint decisions (stackup, keep-outs, netclasses) live in the
build scripts and the verification report; this log records the choices.*

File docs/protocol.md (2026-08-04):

# BLE protocol

Device name `JRWatch`, BLE peripheral, connectable slow advertising
(1-2 s interval). Preferred connection parameters: 50-100 ms interval,
slave latency 4, timeout 4 s, chosen for idle-connected current rather than
latency.

## Services

### Battery Service - standard `0x180F`

| Characteristic | UUID | Access | Format |
|---|---|---|---|
| Battery Level | `0x2A19` | read / notify | uint8, percent |

Fed from the nPM1300 measurement chain (VBAT via the charger's sensor
channels + OCV table; NCS `nrf_fuel_gauge` is the drop-in upgrade).

### Motion Service - custom base `6a570000-8f9d-4a7c-9b31-24d1c30f51aa`

| Characteristic | UUID (short) | Access | Format |
|---|---|---|---|
| Step count | `6a570001-...` | read / notify | uint32 little-endian, steps since boot |
| Activity state | `6a570002-...` | read | uint8: 0 = idle (armed sleep), 1 = active |

Step notifications are emitted only when the value changes and only while a
client has subscribed. There is no periodic radio traffic otherwise.

## Planned (documented, not yet implemented)

- Current Time Service client -> real wall-clock on the face.
- MCUboot + USB DFU for cable updates (flash partitions already laid out).

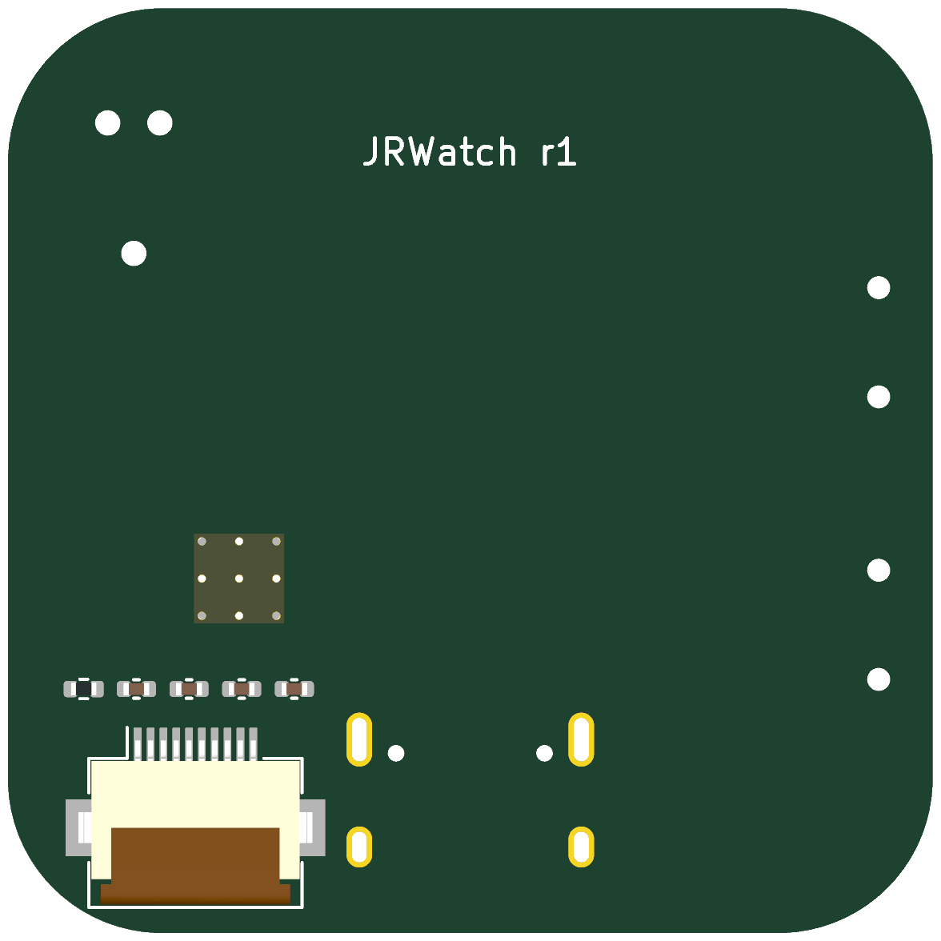
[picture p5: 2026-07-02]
hardware/review/render-top.png

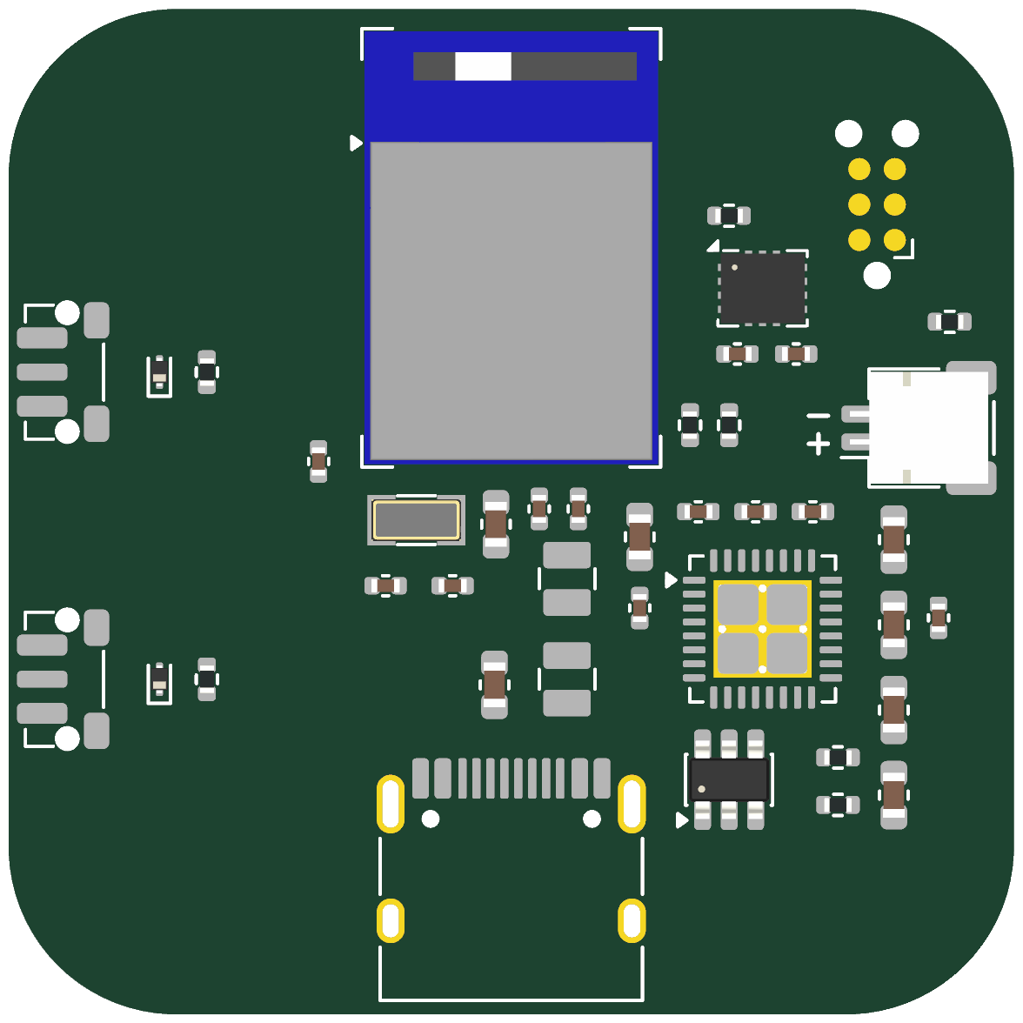
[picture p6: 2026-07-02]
hardware/review/render-bottom.png

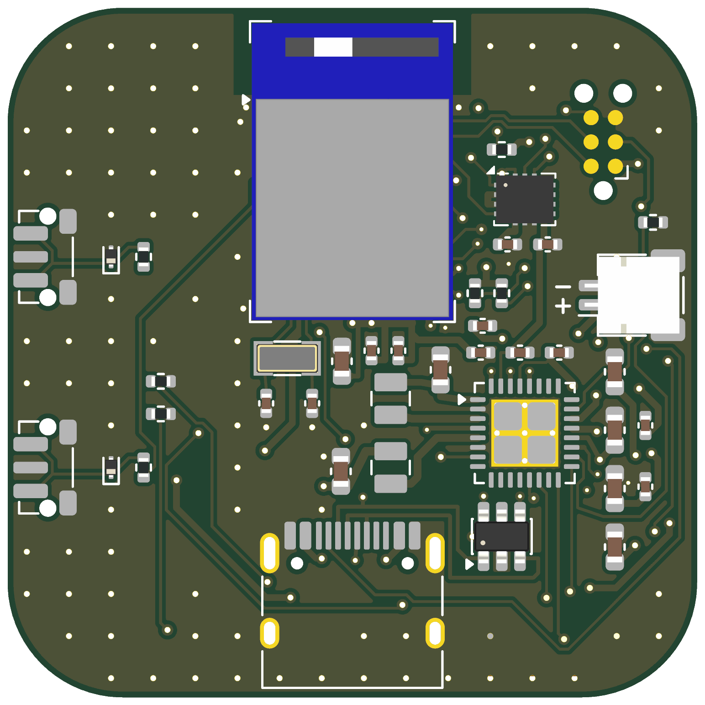
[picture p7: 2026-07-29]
fab/renders/board-bottom.png

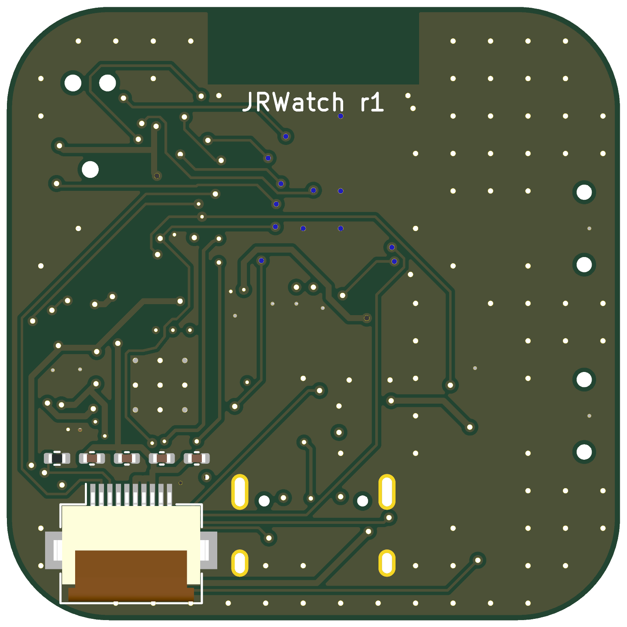
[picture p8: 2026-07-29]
fab/renders/board-top.png

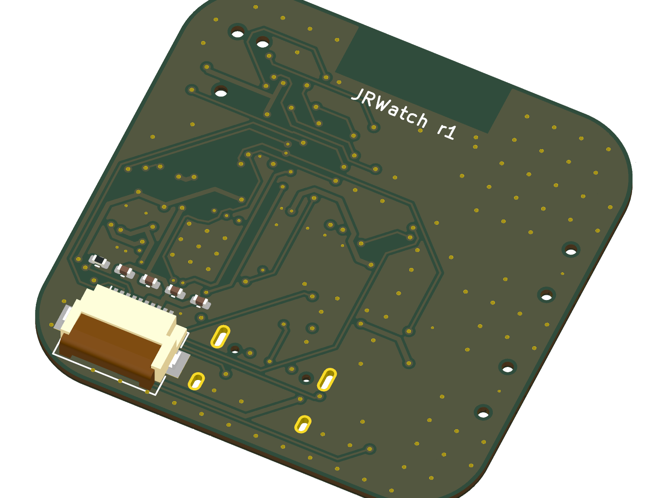
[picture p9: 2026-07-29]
fab/renders/board-iso.png

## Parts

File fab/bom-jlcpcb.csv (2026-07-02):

Comment | Designator | Footprint | LCSC
10uF | C1,C12,C2,C5,C7,C8 | C_0603_1608Metric | C19702
1uF | C10,C20,C22,C6,C9 | C_0402_1005Metric | C52923
100nF | C11,C13,C14,C15,C18,C19,C21,C23,C4 | C_0402_1005Metric | C1525
12pF | C16,C17 | C_0402_1005Metric | C1547
2.2uF | C3 | C_0603_1608Metric | C23630
ESD9B5.0 | D1 | D_SOD-923 | C3008065
ESD9B3.3 | D2 | D_SOD-923 | C96512
TYPE-C-31-M-12 | J1 | USB_C_Receptacle_HRO_TYPE-C-31-M-12 | C165948
FH12A-10S-0.5SH [HAND-PLACE] | J2 | Hirose_FH12-10S-0.5SH_1x10-1MP_P0.50mm_Horizontal | C5139870
SM02B-SRSS-TB | J3 | JST_SH_SM02B-SRSS-TB_1x02-1MP_P1.00mm_Horizontal | C160402
2.2uH | L1,L2 | L_Murata_DFE201612E_2016 | C337893
47k | R1 | R_0402_1005Metric | C25792
150k | R2 | R_0402_1005Metric | C25755
4.7k | R3,R4 | R_0402_1005Metric | C25900
100k | R5,R6 | R_0402_1005Metric | C25741
100R | R7,R8 | R_0402_1005Metric | C25076
10k NTC | RT1 | R_0402_1005Metric | C77131
PWR/SHIP | SW1 | SW_Push_1P1T-MP_NO_Horizontal_Alps_SKRTLAE010 | C110293
USER | SW2 | SW_Push_1P1T-MP_NO_Horizontal_Alps_SKRTLAE010 | C110293
MDBT50Q-1MV2 [HAND-PLACE: DigiKey, LCSC OOS at design time] | U1 | Raytac_MDBT50Q | C5118826
nPM1300-QEAA-R7 [HAND-PLACE: DigiKey, LCSC OOS at design time] | U2 | VQFN-32-1EP_5x5mm_P0.5mm_EP3.5x3.5mm_ThermalVias | C7501206
BMI270 | U3 | Bosch_LGA-14_3x2.5mm_P0.5mm | C2836813
USBLC6-2SC6 | U4 | SOT-23-6 | C7519
32.768kHz | Y1 | Crystal_SMD_3215-2Pin_3.2x1.5mm | C32346

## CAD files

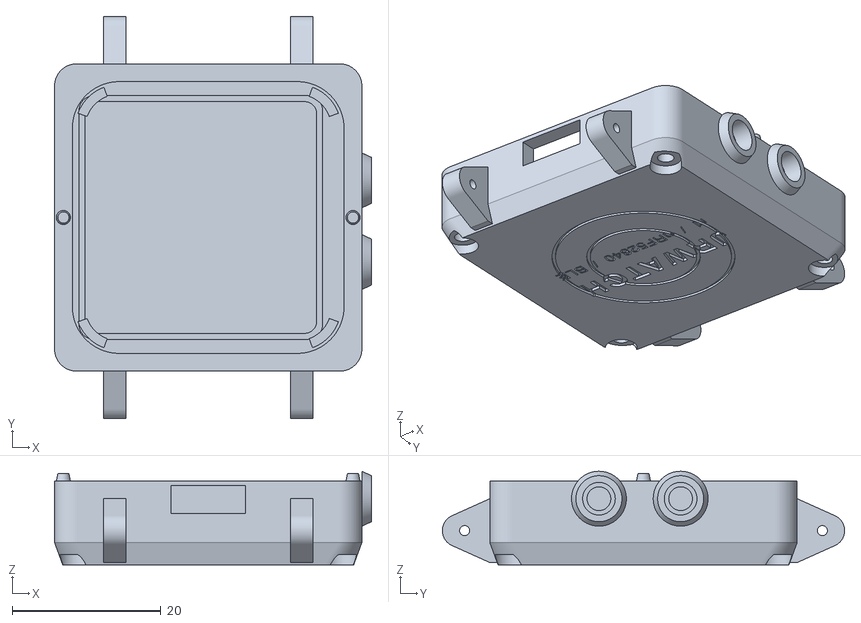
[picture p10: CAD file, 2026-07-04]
hardware/enclosure/stl/case-shell.stl
42.7 x 54.2 x 12.6

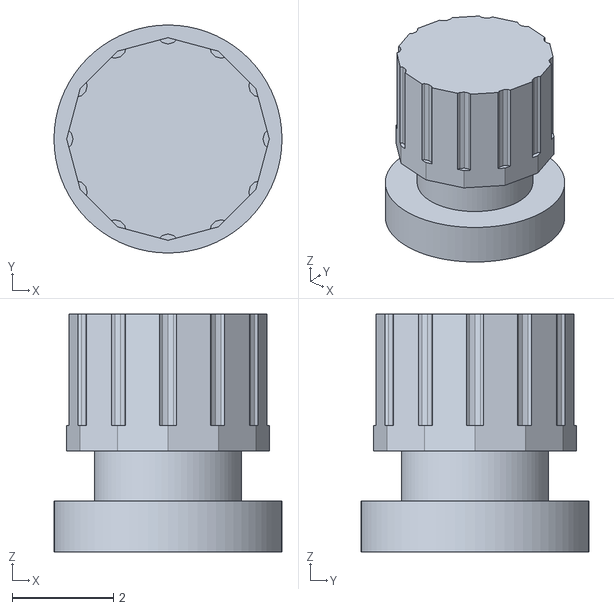
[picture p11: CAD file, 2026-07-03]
hardware/enclosure/stl/case-button.stl
4.50 x 4.50 x 4.69

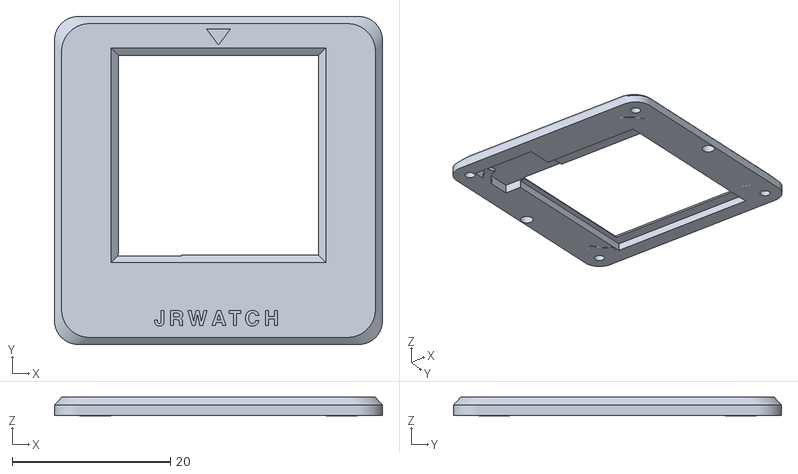
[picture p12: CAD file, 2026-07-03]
hardware/enclosure/stl/case-bezel.stl
41.4 x 41.4 x 2.35

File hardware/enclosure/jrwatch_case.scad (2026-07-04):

// JRWatch enclosure - two-piece 3D-printable watch case
// ------------------------------------------------------
// Dimensions come from the actual board (hardware/jrwatch.kicad_pcb):
//   * board 36 x 36 mm, corner radius 6, thickness 0.8
//   * USB-C on the BOTTOM side, mouth at the south edge, x = 95..105 (board coords)
//   * side buttons SW1/SW2 on the east edge at y = 95 / 106 (board coords)
//   * display LS013B7DH03 on top: 26.6 x 30.3 x 0.74, active 23.04 sq,
//     FPC folds under its south edge into J2
//   * everything else on the bottom, tallest = USB-C shell (3.26)
// Case coordinates: origin at board center, +Y = board north, z=0 case bottom.
//
// Set PART before rendering:
//   "shell"    - bottom case            (print 1x)
//   "bezel"    - top ring               (print 1x)
//   "button"   - side pusher pin        (print 2x)
//   "assembly" - exploded preview       (not for printing)
//   "closed"   - assembled preview
//   "cutaway"  - assembled, sectioned through the USB slot

PART = "assembly";

/* ---------- board & stack ---------- */
board_w   = 36;      // square board edge
board_r   = 6;       // board corner radius
board_t   = 0.8;
clr       = 0.3;     // board-to-case clearance per side

floor_t   = 1.6;
bat_h     = 5.4;     // battery bay: 502030 pouch (5.0) + foam pad
comp_h    = 3.5;     // bottom-component headroom (USB-C shell is 3.26)
bezel_h   = 2.3;     // above board top

z_board   = floor_t + bat_h + comp_h;   // board underside = 10.5
z_part    = z_board + board_t;          // parting line at board top = 11.3
z_top     = z_part + bezel_h;           // 13.6 overall

/* ---------- case body ---------- */
wall      = 2.4;
cav_half  = board_w/2 + clr;            // 18.3
out_half  = cav_half + wall;            // 20.7
out_r     = 3.0;                        // outer corner radius (square-ish corners
                                        // leave meat for the screw bosses)
taper_h   = 3.0;                        // filleted/tapered lower body
taper_in  = 1.1;

/* ---------- screws (M2 x 12 self-tapping, from the back) ---------- */
screw_d    = 17.8;    // hole center at (+/-d, +/-d)
pilot_dia  = 1.7;
shank_dia  = 2.3;
head_dia   = 4.4;
head_h     = 1.4;

/* ---------- display ---------- */
disp_w    = 26.6;                 // x
disp_h    = 30.3;                 // y
disp_t    = 0.74;
disp_tape = 0.3;                  // mounting adhesive under the glass
disp_cy   = (100 - 97.65);        // panel center offset north (board y 82.5..112.8)
ap_size   = 25.2;                 // aperture over the 23.04 active area
ap_cy     = 3.2;                  // active-area center offset north (verify vs
                                  // datasheet fig 8-1 before ordering)

/* ---------- cutouts (from board footprints) ---------- */
usb_w     = 10.0;                 // slot width  (connector 8.94)
usb_zlo   = z_board - 3.6;        // slot bottom (connector hangs 3.26 below board)
usb_zhi   = z_board + 0.2;
btn_hole  = 3.2;                  // pusher pin bore
btn_y     = [ 5, -6 ];            // SW1 (board y=95), SW2 (board y=106)
btn_z     = z_board - 1.6;        // actuator center below the board

/* ---------- strap lugs (22 mm spring-bar strap) ---------- */
lug_gap   = 22.2;                 // between inner prong faces
lug_wide  = 3.0;                  // prong thickness (x)
lug_len   = 5.6;                  // protrusion from wall (y)
bar_hole  = 1.35;                 // spring-bar pin
bar_off   = 3.4;                  // hole center beyond the wall
bar_z     = 4.6;

$fn = 72;
eps = 0.01;

/* ================= 2D helpers ================= */

module rsquare(half, r) { offset(r = r) square(2*(half - r), center = true); }
module cavity2d()  rsquare(cav_half, board_r + clr);
module outer2d()   rsquare(out_half, out_r);

/* ================= shared 3D details ================= */

// crescent screw boss in each corner: post around the screw, clipped so it
// never intrudes on the board's corner arc
module corner_posts(h) {
  for (sx = [-1, 1], sy = [-1, 1])
    scale([sx, sy, 1])
      intersection() {
        linear_extrude(h) intersection() {
          translate([screw_d, screw_d]) circle(d = 5.6);
          cavity2d();
        }
        linear_extrude(h) difference() {
          square(2*out_half, center = true);
          translate([12, 12]) circle(board_r + clr + 0.05);
        }
      }
}

// annular wedge reaching under (or over) the board's corner arc - the board
// is clamped only here; the corner zones are component-free on both sides
module corner_pads(h) {
  for (sx = [-1, 1], sy = [-1, 1])
    scale([sx, sy, 1])
      linear_extrude(h) intersection() {
        translate([12, 12]) difference() { circle(5.9); circle(4.6); }
        translate([12, 12]) rotate(45)
          polygon([[0,0], [10, 4.6], [10, -4.6]]);   // ~50 deg outward wedge
      }
}

// curved watch-style lug horn, drilled for a spring bar
module lug_horn() {
  difference() {
    hull() {
      // root: blends into the case wall
      translate([0, -0.6, 4.6]) cube([lug_wide, 1.2, 8.6], center = true);
      // tip: round horn end
      translate([0, lug_len - 1.4, bar_z])
        rotate([0, 90, 0]) cylinder(h = lug_wide, r = 2.2, center = true);
    }
    translate([0, bar_off, bar_z])
      rotate([0, 90, 0]) cylinder(h = lug_wide + 1, d = bar_hole, center = true);
  }
}

module lugs()
  for (sy = [-1, 1], sx = [-1, 1])
    scale([sx, sy, 1])
      translate([lug_gap/2 + lug_wide/2, out_half - eps, 0]) lug_horn();

// raised pusher guard pods on the east wall
module button_pods()
  for (y = btn_y)
    translate([out_half - eps, y, btn_z]) rotate([0, 90, 0]) {
      cylinder(h = 1.3, d1 = 7.4, d2 = 6.2);
    }

// small alignment nubs on the shell rim (holes in the bezel underside)
nub_p = [[-(cav_half + wall/2), 0], [cav_half + wall/2, 0]];
module rim_nubs()  for (p = nub_p) translate([p[0], p[1], z_part - eps])
                     cylinder(h = 1.0 + eps, d1 = 1.9, d2 = 1.5);

/* ================= bottom shell ================= */

module shell_body() {
  // tapered, edge-filleted lower body flowing into straight walls
  hull() {
    translate([0, 0, 0])       linear_extrude(eps) rsquare(out_half - taper_in, out_r + 0.8);
    translate([0, 0, taper_h]) linear_extrude(eps) outer2d();
  }
  translate([0, 0, taper_h]) linear_extrude(z_part - taper_h) outer2d();
}

module back_engraving() {
  mirror([1, 0, 0]) {                       // reads correctly from outside
    translate([0, 2.6, -eps]) linear_extrude(0.45)
      text("JRWATCH", size = 3.4, font = "Helvetica:style=Bold",
           halign = "center", valign = "center", spacing = 1.15);
    translate([0, -2.6, -eps]) linear_extrude(0.45)
      text("r1  /  nRF52840  /  BLE", size = 1.7, font = "Helvetica",
           halign = "center", valign = "center", spacing = 1.1);
  }
  // decorative recessed rings
  for (r = [7.6, 12.4]) translate([0, 0, -eps]) linear_extrude(0.35)
    difference() { circle(r + 0.25); circle(r - 0.25); }
}

module shell() {
  difference() {
    union() { shell_body(); lugs(); button_pods(); }
    // main cavity
    translate([0, 0, floor_t]) linear_extrude(z_part) cavity2d();
    // screw shank + head pocket
    for (sx = [-1, 1], sy = [-1, 1]) {
      translate([sx*screw_d, sy*screw_d, -eps]) cylinder(h = z_part, d = shank_dia);
      translate([sx*screw_d, sy*screw_d, -eps]) cylinder(h = head_h + eps, d = head_dia);
    }
    // USB-C slot with a port-recess and plug chamfer, south wall
    translate([0, -out_half, (usb_zlo + usb_zhi)/2]) {
      cube([usb_w, 2*wall + 2, usb_zhi - usb_zlo], center = true);
      translate([0, -wall + 0.55, 0]) hull() {
        cube([usb_w + 0.4, wall, usb_zhi - usb_zlo + 0.4], center = true);
        translate([0, -0.9, 0])
          cube([usb_w + 2.4, 0.2, usb_zhi - usb_zlo + 2.2], center = true);
      }
    }
    // stepped pusher bores, east wall (pin inserts from the inside):
    // flange counterbore -> narrow retention bore -> wide channel for the cap
    for (y = btn_y) translate([cav_half - eps, y, btn_z]) rotate([0, 90, 0]) {
      translate([0, 0, -1.2]) cylinder(h = 1.2 + eps, d = 4.9);   // flange seat
      cylinder(h = 1.0 + eps, d = btn_hole);                      // retention bore
      translate([0, 0, 1.0]) cylinder(h = wall + 3, d = 4.4);     // cap channel
    }
    back_engraving();
  }
  // rebuild the corner posts (the cavity cut removed them), minus screw bores
  difference() {
    corner_posts(z_board);
    for (sx = [-1, 1], sy = [-1, 1])
      translate([sx*screw_d, sy*screw_d, -eps]) cylinder(h = z_board + 1, d = shank_dia);
  }
  translate([0, 0, z_board - 1.0]) corner_pads(1.0);   // board rests on these
  rim_nubs();
  // battery fence (502030 pouch + foam pad drop in here)
  translate([-1, 0, floor_t]) linear_extrude(0.8) difference() {
    rsquare(31.2/2 + 0.8, 2);
    rsquare(31.2/2, 1.6);
  }
}

/* ================= top bezel ================= */
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

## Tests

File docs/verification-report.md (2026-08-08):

# Verification Report

This is where I check my own work: every design rule against theory or a
datasheet, with the value and where it came from. Anything marked
**PROJECTED** is calculated from datasheet typicals, not measured. Those get
replaced with real PPK2 measurements at bring-up.

## 1. Headline: power budget and projected battery life

**Projected armed-sleep current: ~ 15 µA (BLE off) / ~ 26 µA (slow advertising).**
**Projected battery life on the 150 mAh cell: ~ 4-8 months per charge in
typical watch use; > 2 years in ship mode (battery self-discharge dominates).**

### Sleep tier budget - "IDLE / armed sleep" (battery side, VBAT = 3.8 V)

Motion-wake armed, watch face statically displayed, RTC running.

| Item | Draw at its rail | Battery-side* | Source |
|---|---|---|---|
| nRF52840 System ON idle, full RAM retention, LFXO + RTC | ~ 3.0 µA @3.0 V | ~ 3.2 µA | nRF52840 PS typicals (ION + RAM retention + ILFXO + IRTC); PROJECTED |
| BMI270 low-power mode, 25 Hz, any-motion armed | 5.9 µA @3.0 V | ~ 6.2 µA | BMI270 DS (BST-BMI270-DS000), low-power mode table |
| Sharp LS013B7DH03 holding static image | 12 µW typ @3.0 V = 4.0 µA | ~ 4.2 µA | Sharp spec §6-4, measurement condition 1 (typ; max 50 µW) |
| nPM1300 quiescent (battery operation) | - | 0.8 µA | nPM1300 PS v1.1 Table 4: IQBAT = 800 nA |
| Strapping/TVS/capacitor leakage | - | ≤ 0.5 µA | D-018: every pull is toward its idle state (0 standing current by design); TVS I_leak ≪ 0.1 µA each |
| **Total (BLE off)** | | **~ 15 µA** | |
| BLE advertising, 1.5 s interval, 0 dBm, DCDC | - | ~ +11 µA | Nordic online power profiler class figure; PROJECTED |
| **Total (slow advertising)** | | **~ 26 µA** | |

\* battery-side = rail current × (3.0 V / 3.8 V) / η, with BUCK2 hysteretic-mode
efficiency taken as η ~ 0.75 at µA loads (PS efficiency curves; PWM-mode spec
is 93 % at 200 mA - light-load hysteretic efficiency is graph-derived and is a
priority bring-up measurement).

### Other tiers

| Tier | Projection | Notes |
|---|---|---|
| Ship mode | 0.37 µA (PMIC) - cell self-discharge (~2-3 %/month) dominates | nPM1300 PS Table 4: IQSHIP = 370 nA; battery fully disconnected from VSYS |
| Hibernate | 0.5 µA | IQSHIPT = 500 nA (wake-timer variant; PMIC capability only - the firmware's three tiers don't use it) |
| ACTIVE (display refresh on change, IMU 50 Hz, BLE connected 100 ms/latency 4) | ~ 250-400 µA avg | dominated by IMU full-ODR (~ 200 µA) + BLE connection events; display redraw is event-driven, ~0 between changes |

### Life projections (150 mAh)

| Profile | Average draw | Projected life |
|---|---|---|
| Armed sleep only, BLE off (worn, no interaction) | 15 µA | ~ 13 months |
| Armed sleep + slow advertising | 26 µA | ~ 240 days |
| Watch use: 30 min/day ACTIVE + advertising idle | ~ 32 µA avg | **~ 6.5 months** |
| Always-connected + hourly interactions | ~ 45 µA avg | ~ 4.5 months |

## 2. RF / antenna - **PASS**

- Keep-out per Raytac Ver.K §2.2-2.3: 12.4 × 3.8 mm, all layers, plus the
  1.6 × 1.2 mm top-layer notch. Implemented three ways and geometrically
  verified from the live board: the module's own two keep-out zones, a
  board-level rule area extending to the edge, and the edge ring. Copper on
  F/In1/In2/B inside the region: **none** (DRC rule areas active throughout
  routing and fills).
- Module placed with the antenna at the board's north edge (Raytac: "place
  the module towards the edge of PCB"). PASS.
- Caveat (checklist §3): keep display tail metal and enclosure screws out of
  the zone too.

## 3. Power / PMIC layout - **PASS with notes**

- Buck loops: SW1/SW2 nodes are 0.4 mm, hand-routed, 4.6 mm long, with the
  output caps (10 µF each) directly at the inductor outputs and PVSS pads on
  the B.Cu ground fill over the In2 plane. Layout follows nPM1300 PS
  reference layout intent. PASS.
- Inductors: 2.2 µH ±20 %, DCR 116 mΩ < 400 mΩ requirement, Isat 2.4 A ≫
  0.2 A buck limit (Murata DFE201612E-2R2M, the part Nordic's EK uses). PASS
  (PS reference BOM).
- Rails: BUCK2 = 3.0 V by VSET2 = 150 kΩ (PS BUCK table) - correct at power-on
  with no firmware dependency; BUCK1 populated per reference config,
  firmware-disabled (D-012, enforced in devicetree + `power.c`). PASS.
- Decoupling: every power pin has its cap; VBUS 10 µF, VBAT 10 µF, VSYS
  10 µF + 2.2 µF, VOUT1/VOUT2 10 µF, VBUSOUT 1 µF, VDDIO 100 nF, LSOUT 1 µF
  each, module VDD 10 µF + 100 nF ×2. Values per PS reference circuitry BOM.
  PASS. *Note:* PVDD's dedicated 100 nF sits on the west bank ~5 mm from the
  pin (pocket congestion); VSYS bulk is 2.6 mm away. Flagged for review.
- **Charge-temperature protection is real hardware**: on-board 10 k B=3380 NTC
  (D-017) matching the devicetree charger config. PASS.
- Load-switch gating: display and IMU rails are LDO1/LDO2 in LDSW mode fed
  from BUCK2 - ship mode can cut both domains to zero. PASS.
- Ground return integrity: review found 16 outer-layer ground islands whose
  component pads had no via to the In2 plane (initially mis-assessed as
  cosmetic). 13 stitch vias added, covering the IMU ground pins, ESD array,
  buttons and most decoupling returns; 3 capacitor islands remain
  (checklist §1). PASS after checklist item closes.

## 4. Sneak-leakage review - **PASS (design), verify at bring-up**

- Every strap pulls toward its net's idle state (D-018): I2C pulls to the
  always-on rail (idle high = 0 µA), CSB pull-up to always-on VDDIO
  (deselected = 0 µA), SCS pull-down (deselected = 0 µA). PASS.
- Display rail off: the panel driver's init is deferred until VDD_DISP is up
  (`zephyr,deferred-init` - at boot nothing drives an unpowered panel), and
  `ui.c` blanks the panel before cutting the rail in the ship path - no
  back-feed through panel input clamps. PASS (code review).
- IMU: VDDIO stays on the always-on rail while VDD is gated - explicitly
  permitted ("no limitations with respect to the voltage level applied to the
  VDD and VDDIO pins", BMI270 DS §POR/supply); interface pins remain defined.
  PASS.
- No LEDs anywhere (D-016). PASS.

## 5. Charge path & IPC-2221 - **external PASS, one In1 neck flagged for the D-025 rework**

Formula: I = k · ΔT^0.44 · A^0.725, k = 0.048 external / 0.024 internal layers.
Worst case is the 500 mA USB input limit (charging + system), ΔT = 10 °C:

- **External sections (1 oz, k = 0.048):** required area
  A = (0.5 / (0.048 × 10^0.44))^(1/0.725) = **6.3 mil²** -> at 1 oz (1.378 mil)
  = **4.6 mil ~ 0.12 mm** minimum width. Implemented: 0.3 mm minimum at the VBUS
  entry (D-019 pinch), 0.35 mm typical on the external runs. **Margin ≥ 2.5×
  on width. PASS.**
- **Internal sections (0.5 oz In1, k = 0.024):** the same formula requires
  **0.60 mm** width for 500 mA at ΔT = 10 °C. The VBUS path's In1 link into the
  PMIC pocket runs **0.35 mm** for ~2 mm outside the In1 pour - that section
  supports ~340 mA at ΔT = 10 °C, and at the full 500 mA computes to ΔT ≈ 24 °C.
  Not a safety issue at an intermittent charge load, but the neck misses the
  10 °C design target: **widen it (or pull it into the pour) in the D-025
  layout rework before ordering.**
- Charge current itself is configured at 76 mA (0.5 C for 150 mAh; devicetree
  `current-microamp = 76000`), where required width is < 0.03 mm - the 500 mA
  case only occurs while USB feeds system + charger concurrently. PASS.
- Battery polarity marked on silk; connector pin 1 = BAT+; PCM-protected pack
  specified. PASS.

## 6. USB - **PASS**

- D+/D- routed as a coupled pair (0.2 mm), one deliberate F.Cu crossover
  strap (the 16-pin connector interleaves the pair; one crossover is
  topologically required - D-log). Summed routed length (connector-side +
  module-side nets, measured from the board file): D+ 33.2 mm vs D- 29.8 mm:
  **skew 3.4 mm ~ 22 ps ≈ 0.03 %** of a Full-Speed bit (83 ns) at
  v ≈ 1.52·10⁸ m/s. Full-Speed USB has no intra-pair skew requirement at this
  scale, so no serpentine was added; the skew is recorded here instead. PASS.
- Controlled impedance: not required at FS over ~25 mm; pair reference is the
  In2 ground plane. PASS (rationale documented).
- ESD: USBLC6-2SC6 in the data path between connector and module, VBUS pin
  protected. PASS.
- CC1/CC2 direct to nPM1300 (internal Type-C sink detection, D-015);
  VBUS at one merged pad pair (D-019). PASS with note.

## 7. Crystal (32.768 kHz) - **refit to 18 pF (D-026); confirm ppm at bring-up**

- CL = 12.5 pF crystal (Epson Q13FC13500004). With per-side load caps C and
  per-side stray Cs, the crystal sees CL_eff = (C + Cs) / 2. The original
  12 pF fit came from misapplying C = 2·(CL - Cs) with the per-side stray:
  with Cs ~ 6.5 pF/side (nRF XL pin ~ 4 pF + PCB ~ 2.5 pF) it gave
  CL_eff ≈ 9.25 pF vs the 12.5 pF spec - tens of ppm fast, i.e. seconds/day.
  The correct fit is C = 2·CL - Cs ≈ 18.5 → **18 pF**, now in the schematic
  source (C16/C17, D-026): CL_eff = (18 + 6.5)/2 ≈ **12.25 pF**, within a
  few percent of spec for any plausible stray. The stray estimate is still
  the softest number here, so measure ppm at bring-up - pads are 0402 and a
  value swap is trivial. Short guarded pair, ground-return vias at the caps.
  Note the checked-in netlist/board/fab outputs still carry 12 pF; they
  regenerate with the D-025 respin (D-026).

## 8. DFM vs JLCPCB 4-layer - **PASS except documented items**

| Rule | JLC capability | This board | Verdict |
|---|---|---|---|
| Min track/space | 0.09 / 0.09 mm | 0.15 mm track / 0.13 mm gap | PASS |
| Min via | 0.15 mm drill / 0.25 pad | 0.2 drill / 0.45 pad (0.48 pad on-column) | PASS |
| Hole-to-hole | 0.5 mm | ≥ 0.5 mm (drill-shrink fix) | PASS |
| Copper-to-edge | 0.2 mm | 0.3 mm + 0.45 ring | PASS |
| Board | 4-layer 0.8 mm | JLC04081H-3313 | PASS |
| DRC | zero violations | **zero under KiCad 10.0.2**; 10.0.5 newly flags 8 hole-clearance pairs, all inside the stock Alps button footprint (its own NPTH locating posts vs its own pads - vendor land pattern) | PASS with note |
| Connectivity | complete | **4 links + 3 ground islands open - documented** (D-022..D-024, checklist §1); power tree complete | **NEEDS REVIEW** |
| BOM stock | all lines LCSC | all verified 2026-07-02; U1/U2 DigiKey hand-place; J2 low stock | PASS with notes |
| Hand-solderability | - | castellated module + QFN/LGA via hot air; 0402 minimum; solid pours noted (D-021) | PASS |

## 9. ERC / netlist - **PASS**

SKiDL ERC: **0 errors, 0 warnings** (`hardware/netlist/erc-report.txt`),
47 parts / 43 nets, pin types assigned from datasheets, netlist -> board pad
mapping by name verified during placement.

## 10. Firmware build - **PASS**

`west build -b jrwatch` green in CI (GitHub Actions, Zephyr CI image
v0.27.4, Zephyr pinned v4.1.0): **flash 237 188 B (22.6 % of 1 MB), RAM
40 816 B (15.6 % of 256 KB)** - MCUboot partition layout already reserved
in the devicetree fits with margin. Build is configuration-verified only;
on-target behavior (BLE, IMU wake, display, PMIC) is a bring-up item.

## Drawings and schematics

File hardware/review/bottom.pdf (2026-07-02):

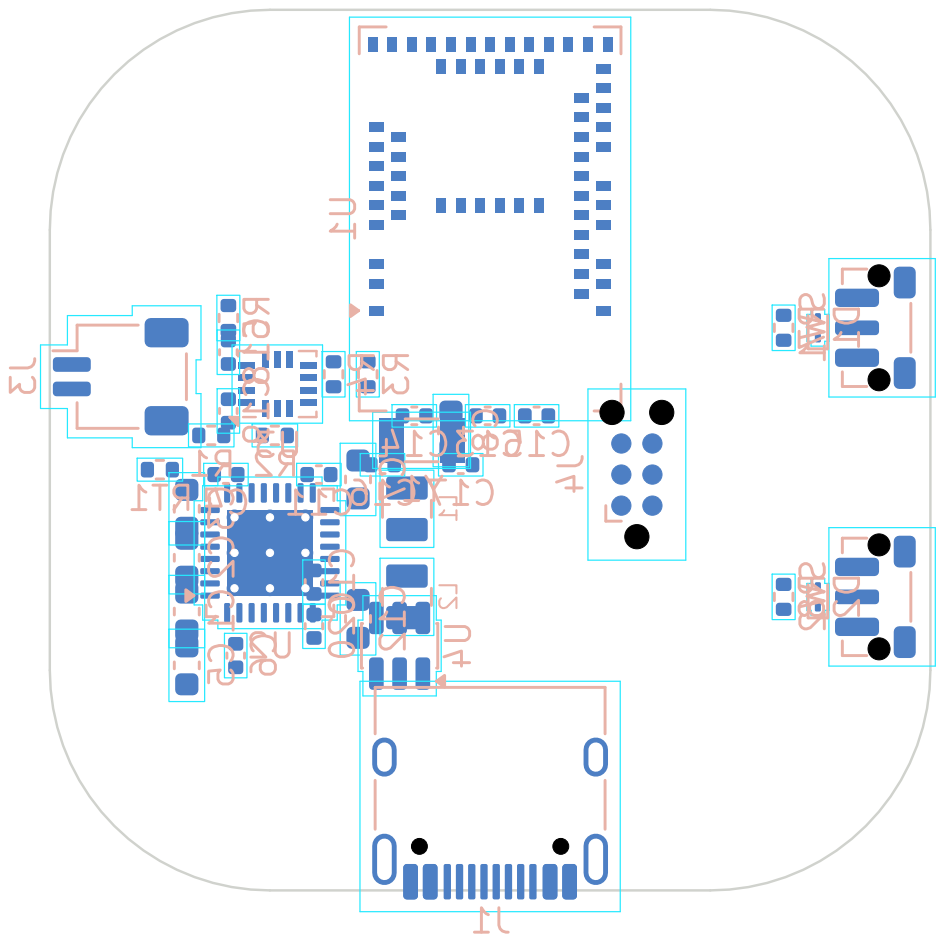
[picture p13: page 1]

Size: A4 | Rev:
KiCad E.D.A. 10.0.2 | Id: 1/1

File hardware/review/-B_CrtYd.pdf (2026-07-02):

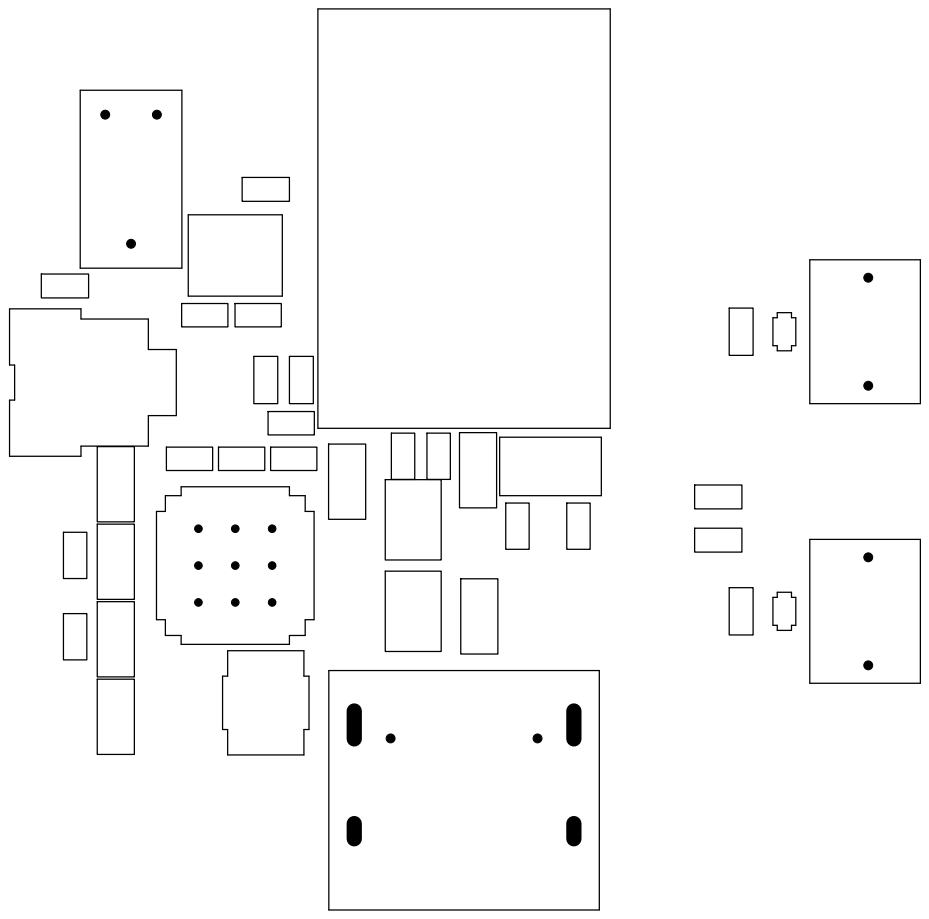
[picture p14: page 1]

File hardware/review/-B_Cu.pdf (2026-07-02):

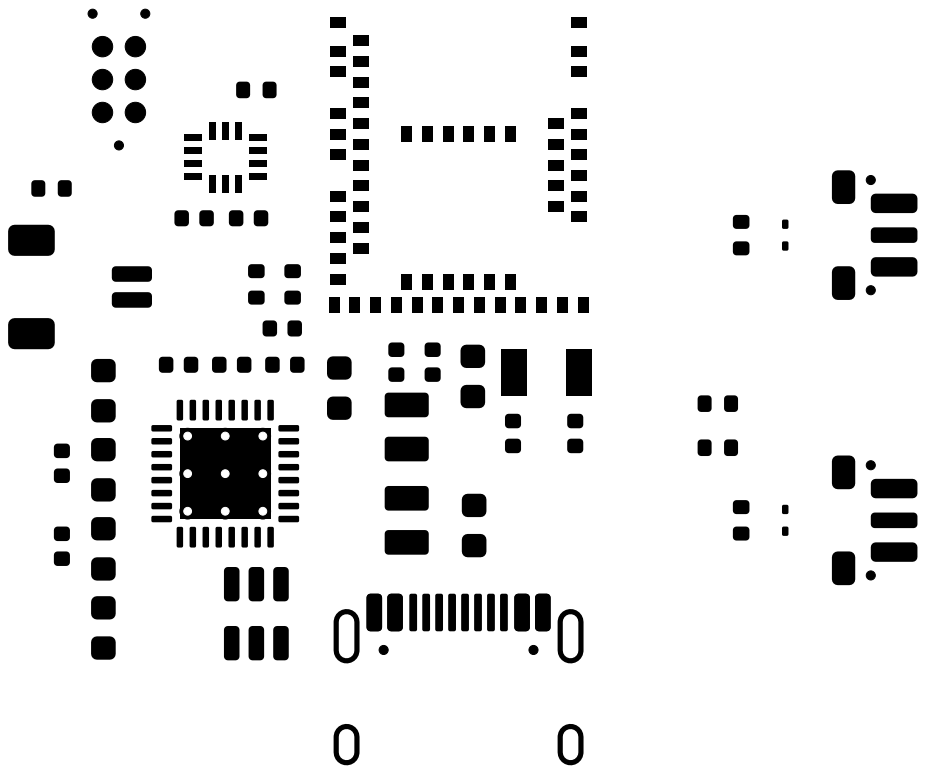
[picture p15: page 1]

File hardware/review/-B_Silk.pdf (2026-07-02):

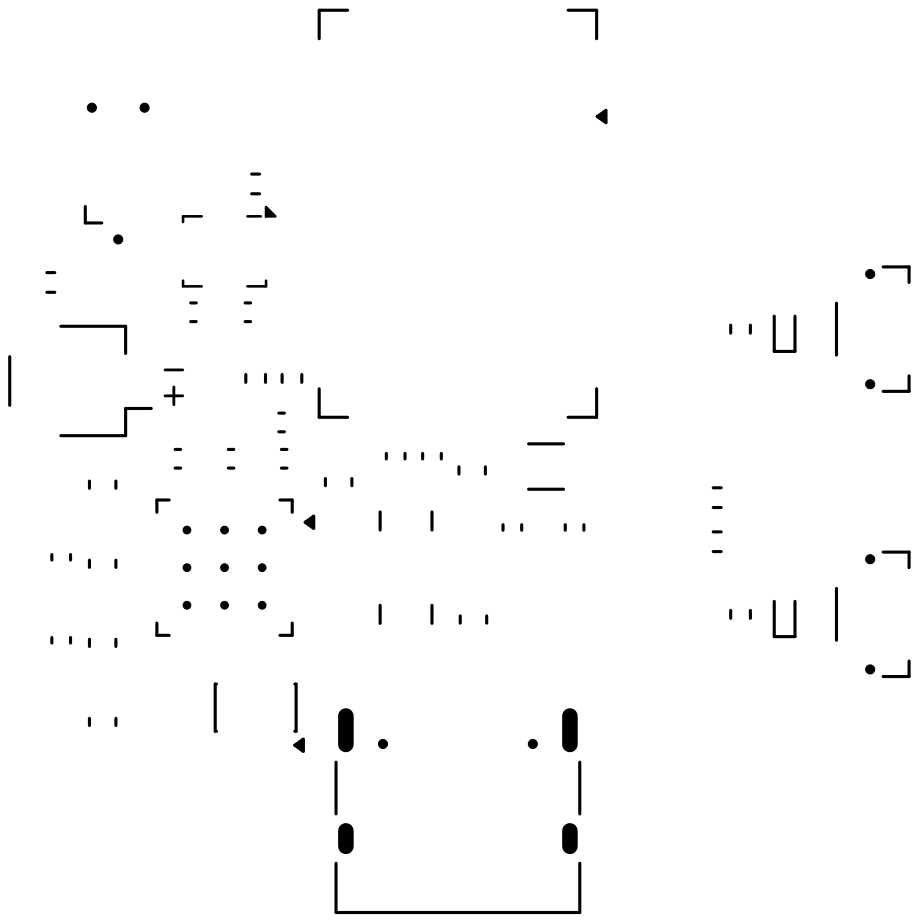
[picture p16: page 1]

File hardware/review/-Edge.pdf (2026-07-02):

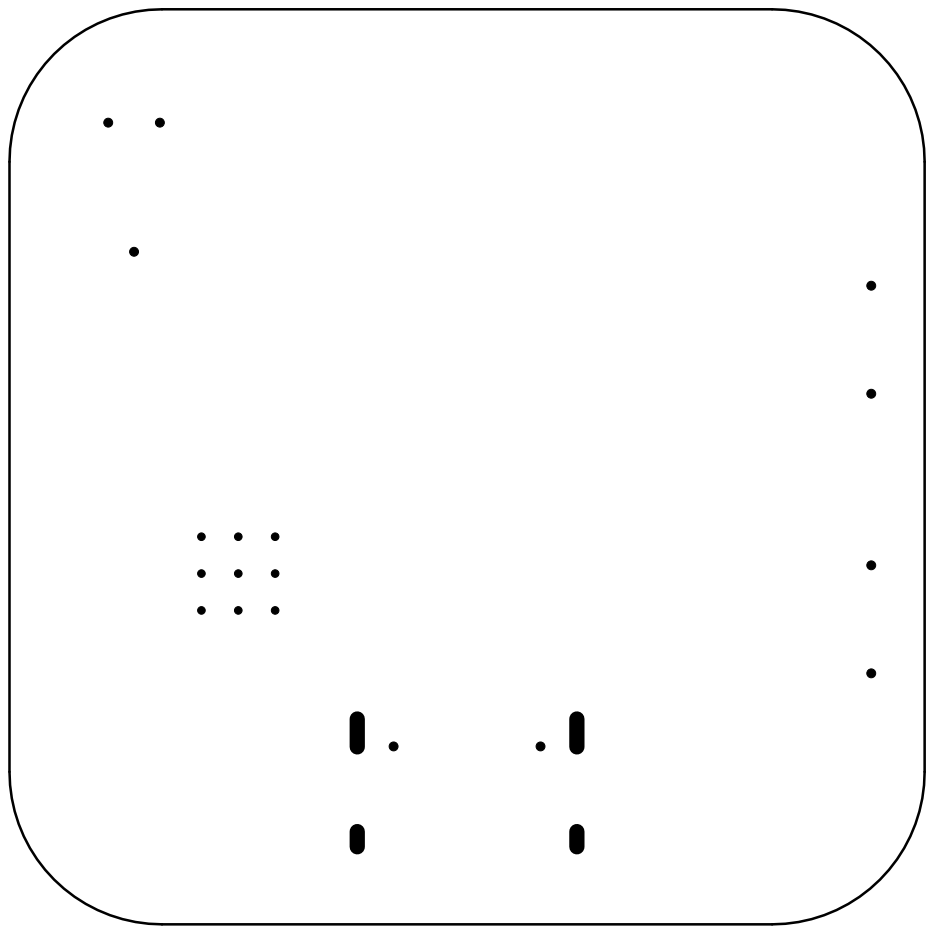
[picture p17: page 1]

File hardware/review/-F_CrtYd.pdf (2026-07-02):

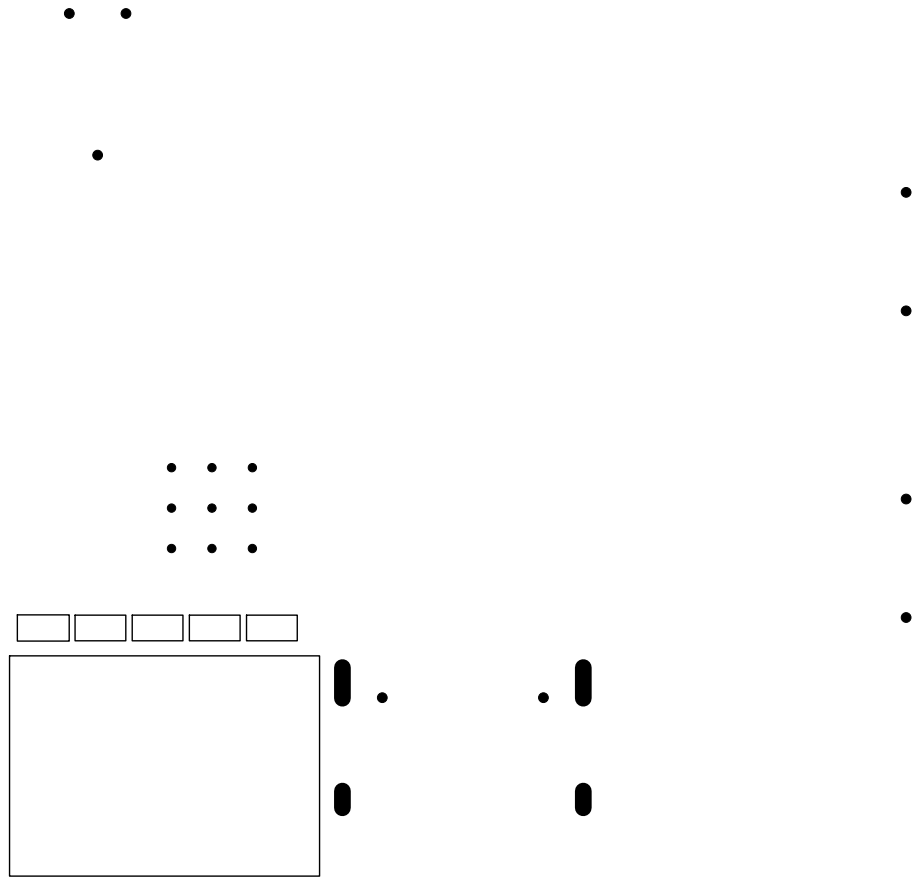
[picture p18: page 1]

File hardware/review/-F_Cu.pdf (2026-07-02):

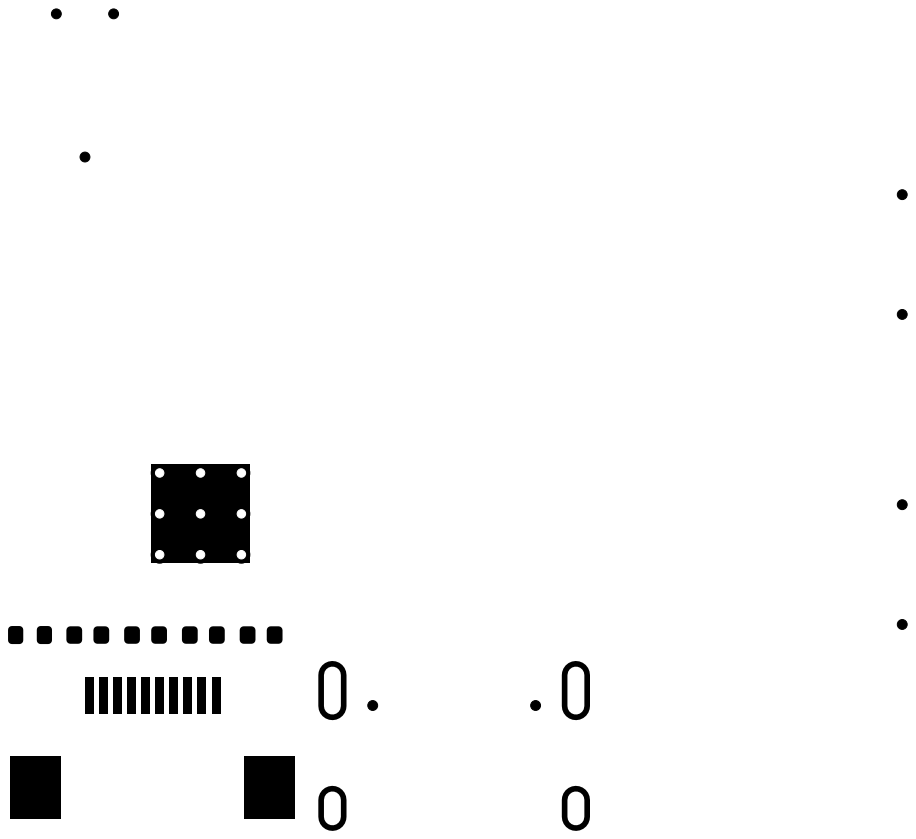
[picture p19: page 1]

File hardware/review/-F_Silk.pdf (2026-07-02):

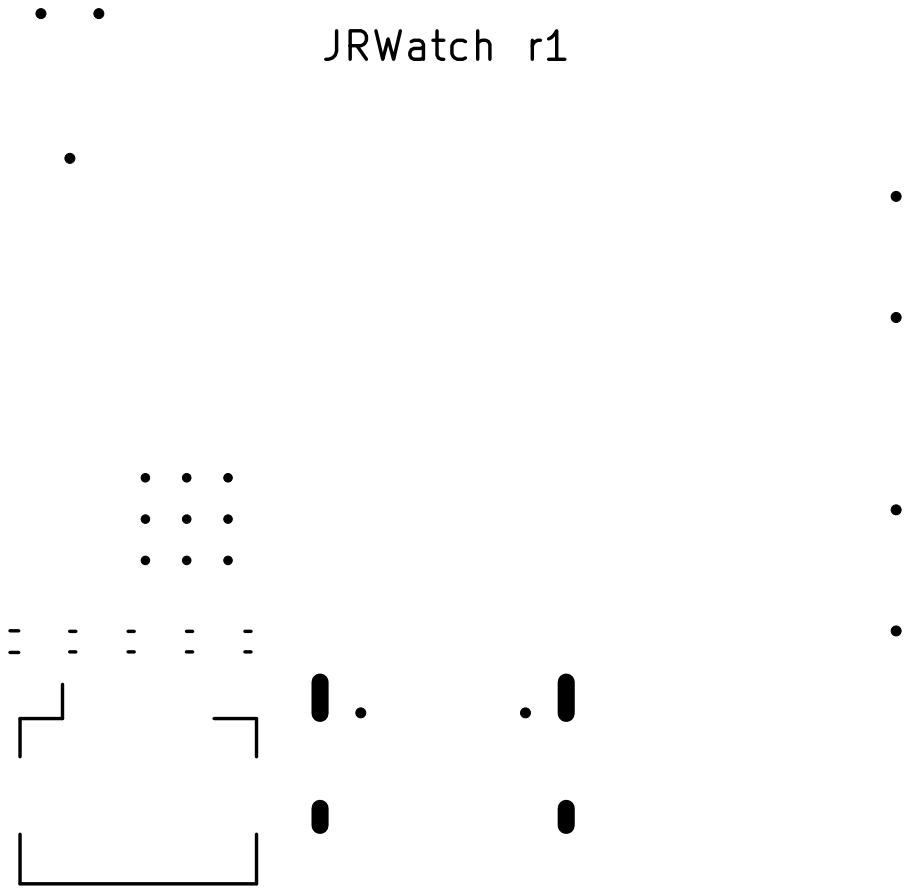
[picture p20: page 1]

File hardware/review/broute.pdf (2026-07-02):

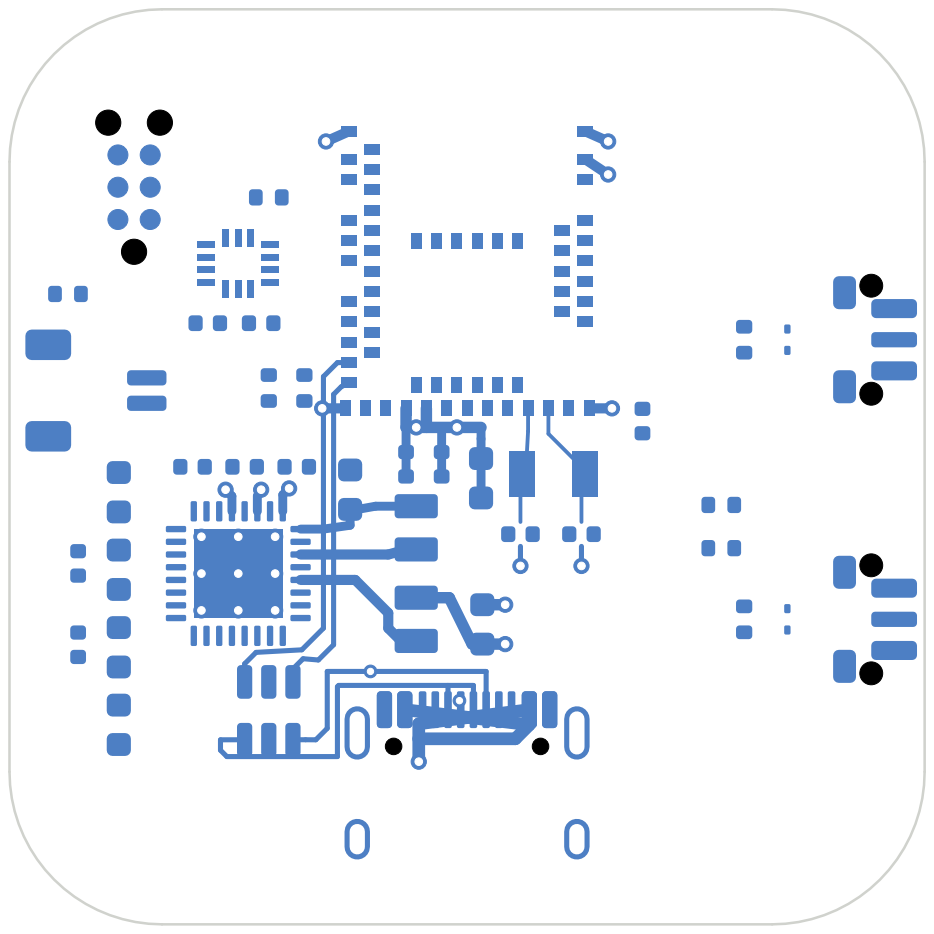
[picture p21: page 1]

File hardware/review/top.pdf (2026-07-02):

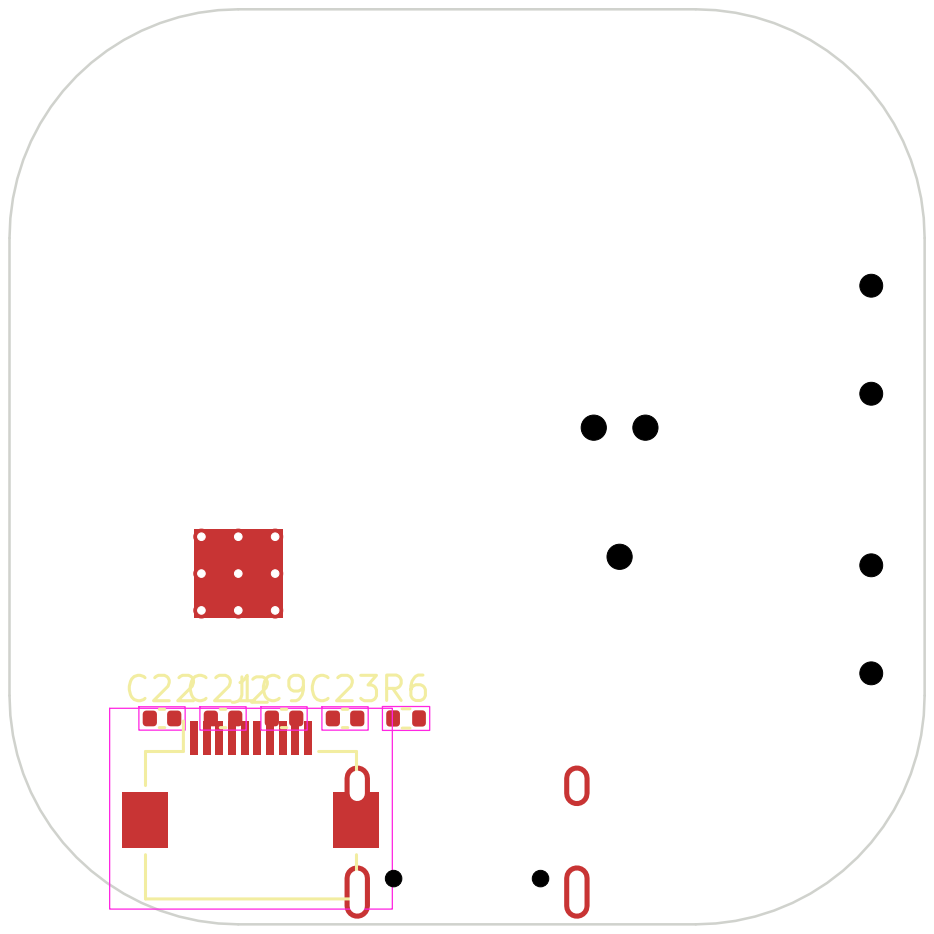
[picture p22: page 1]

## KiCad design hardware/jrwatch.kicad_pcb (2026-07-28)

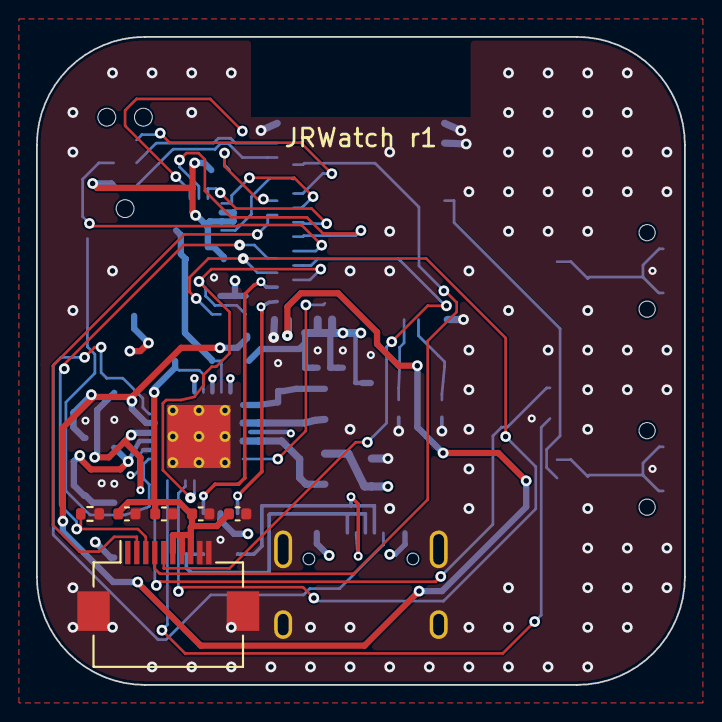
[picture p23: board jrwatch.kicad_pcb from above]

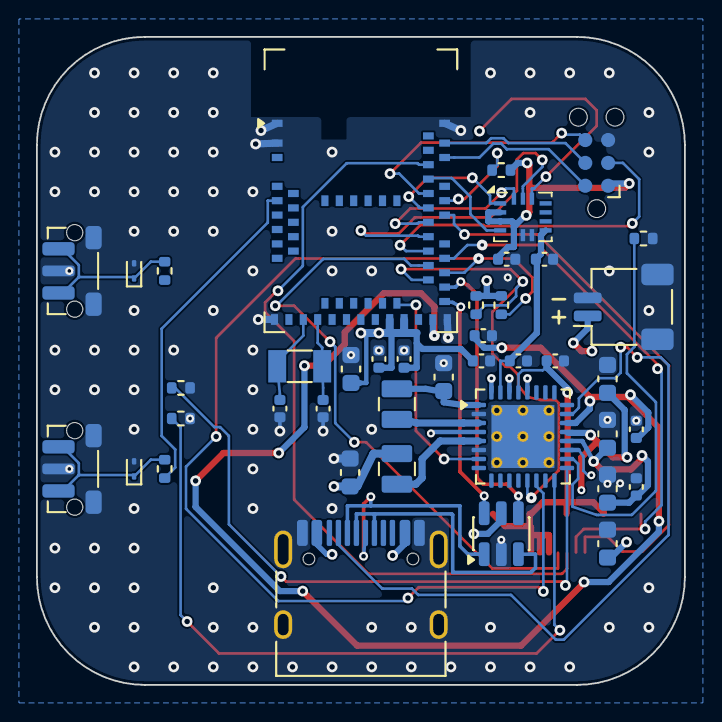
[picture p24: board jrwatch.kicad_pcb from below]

Board: 4 copper layers, 36.0 x 36.0 mm, 47 parts (41 on the bottom side), 43 nets.

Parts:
C1, C2, C5, C7, C8, C12: 10uF; C_0603_1608Metric
C3: 2.2uF; C_0603_1608Metric
C4, C11, C13, C14, C15, C18, C19, C21, C23: 100nF; C_0402_1005Metric
C6, C9, C10, C20, C22: 1uF; C_0402_1005Metric
C16, C17: 12pF; C_0402_1005Metric
D1: ESD9B5.0; D_SOD-923
D2: ESD9B3.3; D_SOD-923
J1: TYPE-C-31-M-12; USB_C_Receptacle_HRO_TYPE-C-31-M-12
J2: FH12A-10S-0.5SH; Hirose_FH12-10S-0.5SH_1x10-1MP_P0.50mm_Horizontal
J3: SM02B-SRSS-TB; JST_SH_SM02B-SRSS-TB_1x02-1MP_P1.00mm_Horizontal
J4: TC2030-IDC-NL; Tag-Connect_TC2030-IDC-NL_2x03_P1.27mm_Vertical
L1, L2: 2.2uH; L_Murata_DFE201612E_2016
R1: 47k; R_0402_1005Metric
R2: 150k; R_0402_1005Metric
R3, R4: 4.7k; R_0402_1005Metric
R5, R6: 100k; R_0402_1005Metric
R7, R8: 100R; R_0402_1005Metric
RT1: 10k NTC; R_0402_1005Metric
SW1: PWR/SHIP; SW_Push_1P1T-MP_NO_Horizontal_Alps_SKRTLAE010
SW2: USER; SW_Push_1P1T-MP_NO_Horizontal_Alps_SKRTLAE010
U1: MDBT50Q-1MV2; Raytac_MDBT50Q
U2: nPM1300-QEAA-R7; VQFN-32-1EP_5x5mm_P0.5mm_EP3.5x3.5mm_ThermalVias
U3: BMI270; Bosch_LGA-14_3x2.5mm_P0.5mm
U4: USBLC6-2SC6; SOT-23-6
Y1: 32.768kHz; Crystal_SMD_3215-2Pin_3.2x1.5mm

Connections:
1V8_AUX: C7.1, L1.2, U2.1
3V0: C8.1, C11.1, C12.1, C13.1, C14.1, C19.1, J4.1, L2.2, R3.2, R4.2, R5.2, U1.28, U1.30, U2.12, U2.28, U2.30, U2.32, U3.2, U3.3, U3.5
BTN1_PAD: D1.1, R7.2, SW1.1
BTN2: R8.1, U1.6
BTN2_PAD: D2.1, R8.2, SW2.1
CC1: J1.A5, U2.23
CC2: J1.B5, U2.24
DISP_CS: J2.3, R6.1, U1.39
DISP_MOSI: J2.2, U1.44
DISP_ON: J2.5, U1.38
DISP_SCK: J2.1, U1.41
EXTCOMIN: J2.4, U1.50
GND: C1.2, C2.2, C3.2, C4.2, C5.2, C6.2, C7.2, C8.2, C9.2, C10.2, C11.2, C12.2, C13.2, C14.2, C15.2, C16.2, C17.2, C18.2, C19.2, C20.2, C21.2, C22.2, C23.2, D1.2, D2.2, J1.A1, J1.A12, J1.B1, J1.B12, J1.SH, J2.9, J2.10, J2.MP, J3.2, J3.MP, J4.5, R1.2, R2.2, R6.2, RT1.2, SW1.2, SW1.MP, SW2.2, SW2.MP, U1.1, U1.2, U1.15, U1.33, U1.55, U2.2, U2.6, U2.33, U3.6, U3.7, U4.2
I2C_SCL: R4.1, U1.37, U2.14
I2C_SDA: R3.1, U1.36, U2.13
IMU_CS: R5.1, U1.46, U3.12
IMU_INT1: U1.49, U3.4
IMU_MISO: U1.45, U3.1
IMU_MOSI: U1.43, U3.14
IMU_SCK: U1.42, U3.13
unnamed: L1.1, U2.3
unnamed: R1.1, U2.17
unnamed: L2.1, U2.5
unnamed: R2.1, U2.16
NTC: RT1.1, U2.18
PMIC_INT: U1.29, U2.7
SHPHLD: R7.1, U2.15
SWDCLK: J4.4, U1.53
SWDIO: J4.2, U1.51
SWO: J4.6, U1.47
USB_DM: U1.34, U4.6
USB_DM_CONN: J1.A7, J1.B7, U4.1
USB_DP: U1.35, U4.4
USB_DP_CONN: J1.A6, J1.B6, U4.3
VBAT: C1.1, J3.1, U2.19
VBUS_OUT: C6.1, C15.1, U1.32, U2.22
VBUS_USB: C5.1, J1.A4, J1.A9, J1.B4, J1.B9, U2.21, U4.5
VDD_DISP: C9.1, C20.1, C21.1, C22.1, C23.1, J2.6, J2.7, J2.8, U2.29
VDD_IMU: C10.1, C18.1, U2.31, U3.8
VSYS: C2.1, C3.1, C4.1, U2.4, U2.20
XL1: C16.1, U1.17, Y1.2
XL2: C17.1, U1.18, Y1.1
nRESET: J4.3, U1.40

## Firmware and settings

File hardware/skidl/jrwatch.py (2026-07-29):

#!/usr/bin/env python3
"""
JRWatch - schematic as code.

Builds the complete netlist, runs ERC, and emits:
  hardware/netlist/jrwatch.net            KiCad netlist
  hardware/netlist/jrwatch-netlist.json   parts+nets for the board build scripts
  hardware/netlist/erc-report.txt         ERC output

Block structure mirrors docs/design-rationale.md:
  power   - nPM1300: USB-C in, LiPo charge path, BUCK1/BUCK2, load switches
  mcu     - MDBT50Q-1MV2 module, 32k crystal, decoupling, Tag-Connect SWD
  usb     - USB-C data pairs through USBLC6 ESD to the module
  imu     - BMI270 on its own SPI, INT1 motion wake
  display - Sharp MIP LCD via 10-pin FPC, gated rail
  controls- SW1 power (SHPHLD), SW2 user (GPIO wake), both ESD-protected
"""
import json
import os
import sys

sys.path.insert(0, os.path.dirname(os.path.abspath(__file__)))

from skidl import Net, ERC, generate_netlist, POWER
# NC and default_circuit are injected into builtins by skidl on import
from parts_lib import (MDBT50Q, NPM1300, BMI270, USB_C, FPC10, JST_SH2, TC2030,
                       USBLC6, XTAL32K, BUCK_L, TACT_SIDE, ESD_3V3, ESD_5V0,
                       NTC10K, C0402, C0603, R0402, PASSIVE_LCSC)

OUT_DIR = os.path.join(os.path.dirname(os.path.abspath(__file__)), '..', 'netlist')
os.makedirs(OUT_DIR, exist_ok=True)

# ---------------------------------------------------------------- global nets
gnd      = Net('GND');       gnd.drive = POWER
vbat     = Net('VBAT');      vbat.drive = POWER      # battery + (J3.1)
vbus_usb = Net('VBUS_USB');  vbus_usb.drive = POWER  # USB-C VBUS -> PMIC
vsys     = Net('VSYS')                               # PMIC power path output
v3v0     = Net('3V0')                                # BUCK2 - always-on system rail
v1v8     = Net('1V8_AUX')                            # BUCK1 - populated, fw-disabled
vbus_out = Net('VBUS_OUT')                           # PMIC VBUSOUT -> module VBUS (5V)
vdd_disp = Net('VDD_DISP')                           # LSW1-gated display rail
vdd_imu  = Net('VDD_IMU')                            # LSW2-gated sensor rail

usb_dp_conn = Net('USB_DP_CONN'); usb_dm_conn = Net('USB_DM_CONN')
usb_dp      = Net('USB_DP');      usb_dm      = Net('USB_DM')
cc1 = Net('CC1'); cc2 = Net('CC2')

i2c_sda = Net('I2C_SDA'); i2c_scl = Net('I2C_SCL')
pmic_int = Net('PMIC_INT')
shphld = Net('SHPHLD')            # PMIC side of power button (swings to VBAT!)
btn2 = Net('BTN2')                # nRF side of user button (3V0 logic)

imu_sck = Net('IMU_SCK'); imu_mosi = Net('IMU_MOSI')
imu_miso = Net('IMU_MISO'); imu_cs = Net('IMU_CS'); imu_int1 = Net('IMU_INT1')

disp_sck = Net('DISP_SCK'); disp_mosi = Net('DISP_MOSI'); disp_cs = Net('DISP_CS')
disp_on = Net('DISP_ON'); extcomin = Net('EXTCOMIN')

swdio = Net('SWDIO'); swdclk = Net('SWDCLK'); nrst = Net('nRESET'); swo = Net('SWO')
xl1 = Net('XL1'); xl2 = Net('XL2')
ntc = Net('NTC')

# ------------------------------------------------------------------- helpers
def _tag(part, kind, value):
    info = PASSIVE_LCSC.get((kind, value))
    if info:
        part.fields['LCSC'], part.fields['MPN'], part.fields['Mfr'] = info
        part.fields['Sourcing'] = 'jlc'
    return part

def cap(value, size='0402'):
    c = (C0603 if size == '0603' else C0402)(value=value)
    return _tag(c, 'C', value)

def res(value):
    return _tag(R0402(value=value), 'R', value)

def decouple(net, *specs):
    """specs: ('100nF','0402') tuples or bare '100nF' strings."""
    for s in specs:
        v, sz = s if isinstance(s, tuple) else (s, '0402')
        c = cap(v, sz)
        c[1] += net
        c[2] += gnd

# ============================================================ POWER (nPM1300)
u2 = NPM1300(ref='U2', value='nPM1300-QEAA-R7')

# charge path & power path
u2['VBAT'] += vbat
u2['VSYS'] += vsys
u2['PVDD'] += vsys                       # bucks fed from system power path
u2['VBUS'] += vbus_usb
u2['VBUSOUT'] += vbus_out
u2['EP_AVSS'] += gnd
u2['PVSS1'] += gnd
u2['PVSS2'] += gnd
decouple(vbat, ('10uF', '0603'))
decouple(vsys, ('10uF', '0603'), ('2.2uF', '0603'), '100nF')
decouple(vbus_usb, ('10uF', '0603'))
decouple(vbus_out, '1uF')

# USB-C CC lines - nPM1300 implements Type-C sink detection internally (D-015)
u2['CC1'] += cc1
u2['CC2'] += cc2

# BUCK1: 1.8 V aux (populated per Nordic ref config 1, disabled by firmware, D-012)
l1 = BUCK_L(ref='L1', value='2.2uH')
u2['SW1'] += l1[1]
l1[2] += v1v8
u2['VOUT1'] += v1v8
decouple(v1v8, ('10uF', '0603'))
r_vset1 = res('47k')                     # VSET1 47k -> 1.8 V startup
u2['VSET1'] += r_vset1[1]
gnd += r_vset1[2]

# BUCK2: 3.0 V system rail - correct at power-on by VSET2 strap (D-012)
l2 = BUCK_L(ref='L2', value='2.2uH')
u2['SW2'] += l2[1]
l2[2] += v3v0
u2['VOUT2'] += v3v0
decouple(v3v0, ('10uF', '0603'))
r_vset2 = res('150k')                    # VSET2 150k -> 3.0 V startup
u2['VSET2'] += r_vset2[1]
gnd += r_vset2[2]

# load switches: LSIN from the 3V0 rail so gated domains see clean 3.0 V
u2['LSIN1'] += v3v0
u2['LSOUT1'] += vdd_disp
decouple(vdd_disp, '1uF')
u2['LSIN2'] += v3v0
u2['LSOUT2'] += vdd_imu
decouple(vdd_imu, '1uF')

# PMIC housekeeping
u2['VDDIO'] += v3v0
decouple(v3v0, '100nF')                  # at VDDIO pin
u2['SDA'] += i2c_sda
u2['SCL'] += i2c_scl
for pull_net in (i2c_sda, i2c_scl):
    r = res('4.7k')
    pull_net += r[1]
    v3v0 += r[2]
u2['GPIO0'] += pmic_int
u2['SHPHLD'] += shphld
for p in ('GPIO1', 'GPIO2', 'GPIO3', 'GPIO4', 'LED0', 'LED1', 'LED2'):
    u2[p] += NC

# battery temperature: on-board NTC at the battery connector (D-017)
rt1 = NTC10K(ref='RT1', value='10k NTC')
u2['NTC'] += ntc
ntc += rt1[1]
gnd += rt1[2]

# battery connector - PIN 1 = BAT+
j3 = JST_SH2(ref='J3', value='SM02B-SRSS-TB')
j3[1] += vbat
j3[2] += gnd
j3['MP'] += gnd

# ======================================================== MCU (MDBT50Q-1MV2)
u1 = MDBT50Q(ref='U1', value='MDBT50Q-1MV2')

u1[28] += v3v0                           # VDD
u1[30] += v3v0                           # VDDH tied to VDD - normal voltage mode
u1[32] += vbus_out                       # VBUS from PMIC VBUSOUT
for gpin in (1, 2, 15, 33, 55):
    u1[gpin] += gnd
decouple(v3v0, ('10uF', '0603'), '100nF', '100nF')   # module VDD + VDDH
decouple(vbus_out, '100nF')

# 32.768 kHz crystal (D-009). Load caps 18 pF per the LFXO budget calc in
# docs/verification-report.md (CL=12.5 pF crystal, ~6.5 pF/side stray; D-026).
y1 = XTAL32K(ref='Y1', value='32.768kHz')
u1[17] += xl1
u1[18] += xl2
# crystal pins are interchangeable; assignment chosen so the placed
# geometry routes without a crossover (XL1 pad sits east of XL2)
y1[2] += xl1
y1[1] += xl2
for xnet in (xl1, xl2):
    c = cap('18pF')
    xnet += c[1]
    gnd += c[2]

# SWD via Tag-Connect
j4 = TC2030(ref='J4', value='TC2030-IDC-NL')
j4[1] += v3v0
j4[2] += swdio;  u1[51] += swdio
j4[3] += nrst;   u1[40] += nrst
j4[4] += swdclk; u1[53] += swdclk
j4[5] += gnd
j4[6] += swo;    u1[47] += swo

# peripheral pin map (mirrored in firmware/boards/jr/jrwatch/jrwatch.dts header)
u1[36] += i2c_sda                        # P0.14
u1[37] += i2c_scl                        # P0.13
u1[29] += pmic_int                       # P0.12
u1[42] += imu_sck                        # P0.19
u1[43] += imu_mosi                       # P0.21
u1[45] += imu_miso                       # P0.23
u1[46] += imu_cs                         # P0.22
u1[49] += imu_int1                       # P0.25
u1[41] += disp_sck                       # P0.17
u1[44] += disp_mosi                      # P0.20
u1[39] += disp_cs                        # P0.15
u1[38] += disp_on                        # P0.16
u1[50] += extcomin                       # P1.02 (LF pin, 1 Hz signal - allowed)
u1[6]  += btn2                           # P1.13 (LF pin, button - allowed)

# unused module pins
u1[31] += NC                             # DCCH - REG0 unused in normal-voltage mode
for spare in (3, 4, 5, 7, 8, 9, 10, 11, 12, 13, 14, 16, 19, 20, 21, 22, 23,
              24, 25, 26, 27, 48, 52, 54, 56, 57, 58, 59, 60, 61):
    u1[spare] += NC

# ================================================================ USB-C DATA
j1 = USB_C(ref='J1', value='TYPE-C-31-M-12')
u4 = USBLC6(ref='U4', value='USBLC6-2SC6')

for p in ('A1', 'A12', 'B1', 'B12'):
    j1[p] += gnd
j1['SH'] += gnd
for p in ('A4', 'A9', 'B4', 'B9'):
    j1[p] += vbus_usb
j1['A5'] += cc1
j1['B5'] += cc2
j1['A6'] += usb_dp_conn; j1['B6'] += usb_dp_conn
j1['A7'] += usb_dm_conn; j1['B7'] += usb_dm_conn
j1['A8'] += NC; j1['B8'] += NC

# ESD array in the data path (flow-through), before the module.
# IO1/IO2 channels are identical; assignment matches placed pad geometry
# (pin1 is the east pad of the south row after the bottom-side flip).
u4[1] += usb_dm_conn                     # IO1
u4[6] += usb_dm                          # IO1'
u4[3] += usb_dp_conn                     # IO2
u4[4] += usb_dp                          # IO2'
u4[5] += vbus_usb
u4[2] += gnd
u1[35] += usb_dp                         # D+
u1[34] += usb_dm                         # D-

# ===================================================================== IMU
u3 = BMI270(ref='U3', value='BMI270')
u3['VDD'] += vdd_imu
u3['VDDIO'] += v3v0                      # always-on: interface stays defined when VDD gated
u3['GND'] += gnd
u3['GNDIO'] += gnd
decouple(vdd_imu, '100nF')
decouple(v3v0, '100nF')                  # at VDDIO pin
u3['SCX'] += imu_sck
u3['SDX'] += imu_mosi
u3['SDO'] += imu_miso
u3['CSB'] += imu_cs
r_csb = res('100k')                      # CSB pull-up: deselected while nRF pins float
imu_cs += r_csb[1]
v3v0 += r_csb[2]
u3['INT1'] += imu_int1
u3['ASDX'] += v3v0                       # aux I/F unused -> VDDIO (DS Table 22)
u3['ASCX'] += v3v0
for p in ('INT2', 'OCSB', 'OSDO'):
    u3[p] += NC

# ================================================================== DISPLAY
# Pin order is MIRRORED vs the panel terminal numbers: the tail folds 180
# degrees under the panel (Sharp Rmk 8-1 forbids bending toward the
# polarizer), which flips the contact face up and reverses left-right as
# seen by the top-contact FH12A. Connector pad k mates panel terminal 11-k
# (Sharp fig 8-1: terminal 1 is on the right in the front view).
j2 = FPC10(ref='J2', value='FH12A-10S-0.5SH')
j2[10] += disp_sck                       # SCLK
j2[9] += disp_mosi                       # SI
j2[8] += disp_cs                         # SCS
r_scs = res('100k')                      # SCS is active-high: pull-down = deselected
disp_cs += r_scs[1]
gnd += r_scs[2]
j2[7] += extcomin
j2[6] += disp_on                         # DISP
j2[5] += vdd_disp                        # VDDA
j2[4] += vdd_disp                        # VDD
j2[3] += vdd_disp                        # EXTMODE=H -> EXTCOMIN pin mode (Sharp Rmk 4-1)
j2[2] += gnd                             # VSS
j2[1] += gnd                             # VSSA
j2['MP'] += gnd
decouple(vdd_disp, '1uF', '100nF', '1uF', '100nF')   # VDD + VDDA pairs

# ================================================================= CONTROLS
# SW1: power button -> SHPHLD only (node swings to VBAT - never to an nRF pin, D-014)
sw1 = TACT_SIDE(ref='SW1', value='PWR/SHIP')
d1 = ESD_5V0(ref='D1', value='ESD9B5.0')
r_sw1 = res('100R')
shphld += r_sw1[1]
btn1_pad = Net('BTN1_PAD')
r_sw1[2] += btn1_pad
sw1[1] += btn1_pad
d1[1] += btn1_pad
d1[2] += gnd
sw1[2] += gnd
sw1['MP'] += gnd

# SW2: user button -> nRF GPIO with internal pull-up (wake from System OFF)
sw2 = TACT_SIDE(ref='SW2', value='USER')
d2 = ESD_3V3(ref='D2', value='ESD9B3.3')
r_sw2 = res('100R')
btn2 += r_sw2[1]
btn2_pad = Net('BTN2_PAD')
r_sw2[2] += btn2_pad
sw2[1] += btn2_pad
d2[1] += btn2_pad
d2[2] += gnd
sw2[2] += gnd
sw2['MP'] += gnd

# ================================================================ OUTPUTS
if __name__ == '__main__':
    ERC()
    # archive the ERC report next to the netlist
    erc_src = os.path.splitext(os.path.basename(__file__))[0] + '.erc'
    if os.path.exists(erc_src):
        os.replace(erc_src, os.path.join(OUT_DIR, 'erc-report.txt'))

    net_file = os.path.join(OUT_DIR, 'jrwatch.net')
    generate_netlist(file_=net_file)

    data = {'parts': [], 'nets': []}
    for p in sorted(default_circuit.parts, key=lambda x: x.ref):
        data['parts'].append({
            'ref': p.ref,
            'value': str(p.value),
            'name': p.name,
            'footprint': str(p.footprint),
            'fields': {k: str(v) for k, v in p.fields.items()
                       if k not in ('F0', 'F1', 'F2')},
        })
    for n in default_circuit.get_nets():
        if not n.pins:
            continue
        data['nets'].append({
            'name': n.name,
            'pins': sorted([[pin.part.ref, str(pin.num)] for pin in n.pins]),
        })
    data['nets'].sort(key=lambda x: x['name'])
    with open(os.path.join(OUT_DIR, 'jrwatch-netlist.json'), 'w') as f:
        json.dump(data, f, indent=1)

    print(f"parts: {len(data['parts'])}  nets: {len(data['nets'])}")
    print(f"wrote {net_file}")

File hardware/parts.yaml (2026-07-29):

# JRWatch parts database - sourcing/stock reference, kept in sync with
# hardware/skidl/parts_lib.py (the library the SKiDL netlist actually consumes).
# stock figures checked on LCSC 2026-07-02 (design time). basic/extended per JLCPCB
# at order time. sourcing: "jlc" = economic SMT assembly, "hand" = hand-place
# (reflow/hot air), module castellations iron-solderable.

parts:
  # ---- Core silicon ----------------------------------------------------------
  U1:
    mpn: MDBT50Q-1MV2
    mfr: Raytac
    desc: BLE module, nRF52840, chip antenna, BT5 certified (FCC/CE/TELEC)
    lcsc: C5118826
    lcsc_stock: 0            # listed, out of stock 2026-07-02
    alt_source: DigiKey MDBT50Q-1MV2 (ships today, ~$8) ; P1MV2 (C5119772) footprint-identical
    footprint: RF_Module:Raytac_MDBT50Q
    sourcing: hand
    datasheet: datasheets/mdbt50q-1mv2.pdf (Ver.K)
  U2:
    mpn: nPM1300-QEAA-R7
    mfr: Nordic Semiconductor
    desc: PMIC - linear LiPo charger, 2x buck, 2x LDO/loadswitch, fuel gauge, USB-C CC, ship mode
    lcsc: C7501206
    lcsc_stock: 0            # listed, out of stock 2026-07-02
    alt_source: DigiKey NPM1300-QEAA-R7 $2.95 (ships today)
    footprint: Package_DFN_QFN:VQFN-32-1EP_5x5mm_P0.5mm_EP3.5x3.5mm_ThermalVias  # EP 3.5mm nom per PS mech spec
    sourcing: hand
    datasheet: https://docs.nordicsemi.com/r/bundle/ps_npm1300 (HTML)
  U3:
    mpn: BMI270
    mfr: Bosch Sensortec
    desc: 6-axis IMU, LGA-14 2.5x3.0mm, low-power any-motion + step counter
    lcsc: C2836813
    lcsc_stock: 11182
    footprint: Package_LGA:Bosch_LGA-14_3x2.5mm_P0.5mm   # stock KiCad lib, geometry verified vs DS §8.3
    sourcing: jlc            # extended part
    datasheet: datasheets/bmi270.pdf (BST-BMI270-DS000-08)
  U4:
    mpn: USBLC6-2SC6
    mfr: STMicroelectronics
    desc: USB ESD array for D+/D-/VBUS
    lcsc: C7519
    lcsc_stock: 23395
    footprint: Package_TO_SOT_SMD:SOT-23-6
    sourcing: jlc

  # ---- Display (hand-attached FPC module; connector is the PCB BOM line) -----
  DS1:
    mpn: LS013B7DH03
    mfr: Sharp
    desc: 1.28" 128x128 Memory-in-Pixel LCD, VDD 2.7-3.3V, 12uW static typ
    lcsc: null               # not an LCSC line; PCB carries J2 only
    alt_source: DigiKey/Mouser/Adafruit (breakout PID 3502 family)
    footprint: none (plugs J2)
    sourcing: hand
    datasheet: datasheets/ls013b7dh03.pdf
  J2:
    mpn: FH12A-10S-0.5SH(55)
    mfr: Hirose
    desc: FPC connector 10P 0.5mm, horizontal, top-contact (display; fold-under mount, D-025)
    lcsc: C5139870
    lcsc_stock: 91           # low - order early. NO drop-in alt: the plain FH12
                             # (C506791) is bottom-contact and cannot mate the
                             # folded-under tail (contact face flips up, D-025)
    footprint: Connector_FFC-FPC:Hirose_FH12-10S-0.5SH_1x10-1MP_P0.50mm_Horizontal
    sourcing: hand

  # ---- Connectors / electromech ----------------------------------------------
  J1:
    mpn: TYPE-C-31-M-12
    mfr: Korean Hroparts
    desc: USB-C receptacle 16P, charge + FS data
    lcsc: C165948
    lcsc_stock: 152505
    footprint: Connector_USB:USB_C_Receptacle_HRO_TYPE-C-31-M-12
    sourcing: jlc
  J3:
    mpn: SM02B-SRSS-TB(LF)(SN)
    mfr: JST
    desc: battery connector, SH 2P 1.0mm right-angle (LiPo w/ PCM, 502030-class)
    lcsc: C160402
    lcsc_stock: 185620
    footprint: Connector_JST:JST_SH_SM02B-SRSS-TB_1x02-1MP_P1.00mm_Horizontal
    sourcing: jlc
  J4:
    mpn: TC2030-IDC-NL (footprint only, no part fitted)
    mfr: Tag-Connect
    desc: SWD programming pads
    lcsc: null
    footprint: Connector:Tag-Connect_TC2030-IDC-NL_2x03_P1.27mm_Vertical
    sourcing: none
  SW1:
    mpn: SKRTLAE010
    mfr: Alps Alpine
    desc: side-actuated tact, 4.5x3.4x3.3mm, 1.6N - power/ship-exit button (SHPHLD)
    lcsc: C110293
    lcsc_stock: 30265
    footprint: Button_Switch_SMD:SW_Push_1P1T-MP_NO_Horizontal_Alps_SKRTLAE010
    sourcing: jlc
  SW2:
    mpn: SKRTLAE010
    mfr: Alps Alpine
    desc: side-actuated tact - user button (nRF GPIO wake)
    lcsc: C110293
    lcsc_stock: 30265
    footprint: Button_Switch_SMD:SW_Push_1P1T-MP_NO_Horizontal_Alps_SKRTLAE010
    sourcing: jlc
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

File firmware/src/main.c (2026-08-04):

/*
 * JRWatch main state machine.
 *
 * The whole application is event-driven: between events the SoC sits in
 * System ON idle (WFI via the Zephyr idle thread) and every peripheral is
 * either gated (display/IMU load switches) or in its lowest device state.
 * The measured/projected budget per state lives in docs/verification-report.md.
 */
#include <zephyr/kernel.h>
#include <zephyr/logging/log.h>
#include <zephyr/drivers/gpio.h>
#include <zephyr/input/input.h>

#include "jrwatch.h"

LOG_MODULE_REGISTER(main, CONFIG_LOG_DEFAULT_LEVEL);

struct jr_status jr_status;
K_EVENT_DEFINE(jr_events);

/* after this long with no motion/button/BLE activity, drop to IDLE */
#define ACTIVE_TIMEOUT   K_SECONDS(20)
/* battery/status refresh cadence while active */
#define ACTIVE_TICK      K_SECONDS(5)
/* very long press of the user button requests ship mode */
#define SHIP_HOLD_MS     5000

static int64_t last_button_down;
static bool button_pressed;

static void button_cb(struct input_event *evt, void *user_data)
{
	ARG_UNUSED(user_data);

	if (evt->code != INPUT_KEY_0) {
		return;
	}
	if (evt->value) {
		last_button_down = k_uptime_get();
		button_pressed = true;
	} else {
		/* only honor a release whose press edge we saw; an unpaired
		 * release would compare against a zero timestamp and request
		 * ship mode spuriously */
		if (button_pressed &&
		    k_uptime_get() - last_button_down >= SHIP_HOLD_MS) {
			LOG_INF("long press -> ship mode");
			/* runs on the main loop, not here: ship entry can
			 * block ~100 ms probing for refusal, too long for
			 * the input callback context */
			k_event_post(&jr_events, JR_EVT_SHIP);
		}
		button_pressed = false;
	}
	k_event_post(&jr_events, JR_EVT_BUTTON);
}
INPUT_CALLBACK_DEFINE(NULL, button_cb, NULL);

static void enter_active(void)
{
	jr_status.state = JR_STATE_ACTIVE;
	jr_power_imu_rail(true);
	jr_motion_active();
	jr_ui_display_power(true);
	jr_power_sample();
	jr_ui_render();
	LOG_INF("state: ACTIVE");
}

static void enter_idle(void)
{
	jr_status.state = JR_STATE_IDLE;
	/* display keeps its last frame at ~µW: MIP retains the image and the
	 * EXTCOMIN 1 Hz toggle is driven by the display driver from a timer.
	 * The IMU drops to its 25 Hz low-power any-motion mode (~6 µA). */
	jr_motion_arm_wake();
	jr_ui_render();          /* final face refresh before going quiet */
	LOG_INF("state: IDLE (armed sleep)");
}

int main(void)
{
	int64_t last_activity = k_uptime_get();

	LOG_INF("JRWatch r1 firmware boot");

	(void)jr_power_init();
	/* Both gated rails are boot-off and their peripherals' drivers are
	 * deferred-init (jrwatch.dts): bring VDD_IMU up before probing the
	 * BMI270; VDD_DISP comes up inside jr_ui_display_power(). */
	jr_power_imu_rail(true);
	k_msleep(2);            /* BMI270 POR after rail-up */
	(void)jr_ui_init();
	(void)jr_motion_init();
	(void)jr_ble_init();

	enter_active();

	while (1) {
		uint32_t ev = k_event_wait(&jr_events,
					   JR_EVT_MOTION | JR_EVT_BUTTON |
					   JR_EVT_TICK | JR_EVT_SHIP,
					   false, ACTIVE_TICK);
		k_event_clear(&jr_events, ev);

		if (ev & JR_EVT_SHIP) {
			/* does not return unless entry is refused (USB
			 * power); on refusal fall through and let the
			 * BUTTON bit wake the face back up */
			jr_power_ship_mode();
		}

		if (ev & (JR_EVT_MOTION | JR_EVT_BUTTON)) {
			last_activity = k_uptime_get();
			if (jr_status.state == JR_STATE_IDLE) {
				enter_active();
			}
		}

		if (jr_status.state == JR_STATE_ACTIVE) {
			/* steps accumulate from motion.c's 50 Hz work item */
			jr_power_sample();
			jr_ui_render();
			jr_ble_notify_steps(jr_status.steps);

			if (k_uptime_get() - last_activity >
			    k_ticks_to_ms_floor64(ACTIVE_TIMEOUT.ticks)) {
				enter_idle();
			}
		} else {
			/* IDLE: the timeout wake is just the RTC, so re-render
			 * to keep the face's minute current (no-op unless the
			 * frame content actually changed) */
			jr_ui_render();
		}
	}
	return 0;
}

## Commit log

2026-07-02 Part selection: verified LCSC sourcing, datasheet-derived constraints (D-010..D-018)
    Every BOM line checked against LCSC stock 2026-07-02. Module + PMIC listed
    but OOS at LCSC -> DigiKey-sourced hand-place lines, C-numbers recorded for
    future assembly runs. Antenna keep-out, VSET strapping, button domains, and
    bus strapping rules extracted from datasheets.
2026-07-02 Schematic as code: SKiDL netlist, ERC clean (0 errors, 0 warnings)
    47 parts / 43 nets. Custom part library pin-mapped from datasheets
    (module Ver.K table, nPM1300 PS, BMI270 Table 22, Sharp Table 4).
    Emits KiCad netlist + JSON consumed by the board build scripts.
    [jrwatch.py, jrwatch_sklib.py, parts_lib.py]
2026-07-02 Board build tooling: custom inductor footprint, pcbnew builder with placement plan
    BMI270 switched to stock KiCad Bosch LGA-14 (geometry verified against DS 8.3
    drawing pad-for-pad). Murata 2016 inductor land derived per IPC-7351B nominal,
    flagged for review. Board script: 4-layer setup, JLC-derived DRC minimums,
    net classes, rounded-square outline, anchored placement, antenna keep-out
    extension to board edge.
2026-07-02 Placement complete: 47 parts, zero DRC violations
    pcbnew flip semantics debugged (Flip() encodes LR as mirror+180; rotation
    must be set before flipping). Placement to measured courtyard envelopes.
    Antenna keep-out at north edge (module zones + board rule area to edge),
    USB-C south, buttons east, battery west, PMIC cluster with tight buck
    loops, refdes silk hidden, battery polarity marked.
    [jrwatch.kicad_pcb]
2026-07-02 Critical-net routing clean: USB pair, buck loops, crystal, VBUS entry, pours
    Hand-constrained routes verified to zero DRC conflicts before autorouting.
    Debug trail: QFN top row numbers right-to-left after flip, rot-90 passives
    put pad1 south, USB-C A/B pads land mirrored — every hardcoded coordinate
    re-derived from measured pad positions. One deliberate F.Cu crossover for
    the interleaved USB pair; long USB run rides the empty top layer. USB skew
    7.0mm = 46ps, 0.06% of a FS bit — documented, no serpentine.
    [jrwatch.kicad_pcb]
2026-07-02 Autoroute round 3: planes locked, edge ring; zero conflicts, links pending
    Freerouting cannot stitch into power planes, so plane-net pads and a few
    congested signals remain open (completion router next). Edge keep-out ring
    added structurally; In1/In2 exported as power layers.
    [jrwatch.kicad_pcb]
2026-07-02 Completion-router toolkit: raster A*, pocket surgery, plane taps
    Grid A* over F/B copper with measured rectangular-pad clearances plus the
    hand-derived QFN pocket surgery (on-column 0.48/0.2 vias between pad
    columns reach the In1 3V0 pour directly; pin29/31 thread the freed lanes).
    Board file kept at the round-3 autoroute state — the experimental net-rip
    regressed and was discarded; completion replay runs next.
2026-07-02 Board frozen: zero DRC violations; 7 links documented for interactive completion
    Final state: all critical nets hand-routed and locked, autoroute imported
    clean, pocket surgery connects LSIN/VOUT2/VDD_DISP/VDD_IMU via on-column
    0.48/0.2 vias, hole-to-hole trio fixed by drill shrink, SDA re-routed
    around the new vias. Remaining: 7 U2-adjacent links + GND island stitches,
    each with exact endpoints and a suggested fix in the review checklist —
    left open deliberately rather than routed with violations.
    [jrwatch.kicad_pcb]
2026-07-02 Fab package: JLCPCB gerbers/drill, BOM+CPL, renders, schematic reference
    BOM verification pass corrected three passive C-numbers (12pF C1547,
    47k-1% C25792, 150k-1% C25755 — the original candidates decoded to wrong
    values). Order gated on closing the 7 documented links first (fab/README).
    [bom-jlcpcb.csv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]
2026-07-02 Zephyr firmware: custom board, BLE BAS+motion GATT, IMU wake, MIP UI, PMIC PM
    Custom HWMv2 board (boards/jr/jrwatch) pin-mapped 1:1 from the SKiDL
    schematic. Event-driven state machine: ACTIVE / IDLE(armed sleep) / PMIC
    ship mode; display redraws only on content change; VDD_DISP/VDD_IMU gated
    via nPM1300 load-switch regulators; BUCK1 held off per D-012; LFXO clock
    source; RTT console (no UART pins). CI builds with west against Zephyr
    v4.1.0 in the official container.
2026-07-02 Firmware DTS: required charger discharge limit (200 mA)
2026-07-02 Docs: verification report with power budget, design rationale, protocol, final README
    Headline: ~15 uA projected armed-sleep (itemized, datasheet-cited:
    nPM1300 IQBAT 800nA/ship 370nA from PS v1.1, BMI270 5.9uA, Sharp MIP
    12uW, nRF System ON idle), 4-8 months projected on 150mAh. IPC-2221
    charge-path calc, USB skew analysis, sneak-leakage review, honest
    NEEDS-REVIEW accounting. Decision log D-019..D-022.
2026-07-02 Docs: CI green — badge + measured flash/RAM in README and verification report
2026-07-02 Close PMIC power links: VBAT, VSYS x2 via pocket reshuffle, zero DRC
    [jrwatch.kicad_pcb]
2026-07-02 Ground island stitching: 13 of 16 islands via-stitched to In2 plane, zero DRC
    [jrwatch.kicad_pcb]
2026-07-02 Fab outputs regenerated after link closure and ground stitching
2026-07-02 Enclosure: parametric OpenSCAD two-piece case, printable STLs, ordering and assembly notes
    [case-bezel.stl, case-button.stl, case-shell.stl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]
2026-07-03 Enclosure v2: tapered body, lug horns, knurled pushers, engravings, four-view render set
    [case-bezel.stl, case-button.stl, case-shell.stl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]
2026-07-03 Display connector correction: mirrored J2 pinout (Sharp fig 8-1 fold analysis), ERC 0/0; D-025 layout rework spec; board kept at last clean state
    [jrwatch.py, jrwatch_sklib.py, parts_lib.py]
2026-07-04 Cleaned up punctuation and formatting across docs and comments
    [case-shell.stl, jrwatch_case.scad]
2026-07-18 Docs: tighten README and trim working notes from the published tree
    README rewritten for a reader landing on the repo cold: lead with the
    design target and the measured/projected numbers, drop the process
    preamble, cut the open-task list.
    Working notes (review checklist, open-input tracker, enclosure pre-order
    checks) move out of the tree and are ignored; they were operator notes,
    not part of the design record. Fab and enclosure READMEs lose their
    task lists; remaining references repointed.
    Also drops committed tool logs and REPL scratch output.
    [parts.yaml]
2026-07-18 README: cut to essentials
2026-07-18 README: add board and case renders; trim enclosure feature list
2026-07-18 README: 2D copper plots instead of 3D board renders
2026-07-28 Docs/data audit pass: fix every claim that drifted from the artifacts
    Full re-verification of docs against the schematic source, netlist, board
    copper, and firmware turned up a set of stale or wrong claims:
    - parts.yaml: D1 was still the pre-fix 3.3 V TVS (schematic/BOM/netlist all
    use ESD9B5.0, C3008065 - SHPHLD rides the battery domain); J2 mislabeled
    bottom-contact and endorsed the plain FH12 as substitute, which cannot
    mate the folded-under tail (D-025); header no longer claims single-source-
    of-truth status it didn't have
    - decision log: D-005 stated the buck assignment backwards (BUCK2 is the
    3.0 V system rail); D-007 R9 -> R6 and In1/In2 contents swapped; D-013/D-014
    alig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
    [jrwatch.kicad_pcb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]
2026-07-28 Firmware: fix boot-order init on gated rails, adv restart, step sampling
    Audit of the power/init sequencing found the gated-rail design and the
    driver init order fighting each other:
    - BMI270 and the Sharp panel sit on boot-off load switches, but their
    Zephyr drivers probed at POST_KERNEL against unpowered chips and stayed
    failed forever - motion wake and steps were dead on any cold boot, and
    the panel got SPI traffic while unpowered. Both nodes are now
    zephyr,deferred-init; main() raises VDD_IMU before jr_motion_init()
    probes the chip, and jr_ui_display_power() probes the panel after its
    rail settles.
    - Advertising was restarted inside the disconnected callback, where the
    dyi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
    [main.c]
2026-07-28 Docs: size figures from the current CI build (237188 B flash / 40816 B RAM)
2026-07-29 Fab outputs actually regenerated from the current board
    The earlier "fab outputs regenerated" commit only committed a router log,
    so the renders and gerbers still showed the board from before the link
    closure and ground stitching. Re-plotted everything from the live board
    with kicad-cli (same recipes as the originals, verified against their
    structure and headers):
    - copper-plot SVGs: identical layer sets, page mode, and drill marks;
    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
    [jrwatch-B_Cu.gbl, jrwatch-B_Mask.gbs, jrwatch-B_Paste.gbp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]
2026-07-29 Ship-mode entry, INT1 polarity, long-press guard; LFXO caps refit (D-026)
    - Ship mode now enters true ship (TASKENTERSHIPMODE via the regulator
    parent) instead of hibernate with a zero wake timer, matching the
    IQSHIP figure the power budget quotes. Entry runs from the main loop,
    detects refusal (USB power) and recovers instead of parking the
    input callback context in k_sleep(K_FOREVER). The IMU rail stays up
    through the attempt so a refused entry doesn't lose the BMI270's
    loaded config.
    - Long-press requires a matching press edge; an unpaired release no
    longer compares against a zero timestamp and requests ship mode.
    - BMI270 INT1 flagged active-low: the in-tree driver leaves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
    [jrwatch.py, main.c, parts.yaml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]
2026-07-31 Fix display re-power path, gate ship entry on VBUS; docs cleanup
    - jr_ui_display_power(true) ran cfb_framebuffer_init on every rail-up;
    CFB allocates its buffer from the 4 KB heap each time and never
    frees, so the second power-up (refused ship recovery) failed -ENOMEM
    and left the face permanently blank with the rail refcount stranded.
    CFB now inits once; re-power repaints panel RAM before unblanking
    (ls0xx only clears it at first probe), and a failed power-up releases
    the rail.
    - Ship entry checks VBUS first (live register read via the charger's
    VBUS_PRESENT attribute) and refuses locally - the PS forbids writing
    TASKENTERSHIPMODE with VBUS present, and a latched request wou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
2026-08-03 README: rewrite in plainer language, fix a few overclaims
    Rewrote the front page so it reads the way I'd actually explain the
    project. Also corrected some things the old wording got wrong or
    oversold: the board isn't fabricated, DRC clean against JLCPCB's
    published rules is my own check and not a manufacturer's, and the
    capture pulse rides a dedicated GPIO line rather than I2C.
2026-08-04 Docs: plainer wording throughout
    Rewrote the README in a plainer register and swept the rest of the
    repo for the same: replaced dashes used as punctuation, dropped the
    stock phrasings, and cut a few lines that read like product copy.
    Only comments and docstrings changed in source files. No technical
    content, numbers, or claims were altered.
    [main.c]
2026-08-06 D-025: record that the logged position needs the MP trim to work
    The entry read as though (100, 107.75) was verified good. It is not,
    with the stock footprint: J2's mounting tabs and the USB-C pad field
    overlap, and DRC is silent because both are GND. Noting what actually
    resolves it and what is still unrouted.
2026-08-08 Docs: drop routing-process narration
    The decision log and verification report say what is open, why it is
    blocked, and what was verified. The published record does not need a
    walkthrough of how the copper got placed, so that commentary is gone.
    D-025's open items now state the geometry that blocks them (0.5 mm QFN
    pitch, and the In1 3V0 pour starting east of pin 12) instead.
2026-08-18 Move internal tooling out of the published tree
    Generation and verification scripts move to private/ (already
    gitignored) with the working notes. The design record keeps the
    schematic source, board, fab package, firmware and docs.
